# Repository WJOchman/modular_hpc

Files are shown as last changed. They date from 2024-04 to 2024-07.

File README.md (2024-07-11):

# Design & Development of a Modular High-Performance Computer (HPC)
## ELEE1119 Advanced Computer Engineering | Academic Year 2023/24
<p align="center">
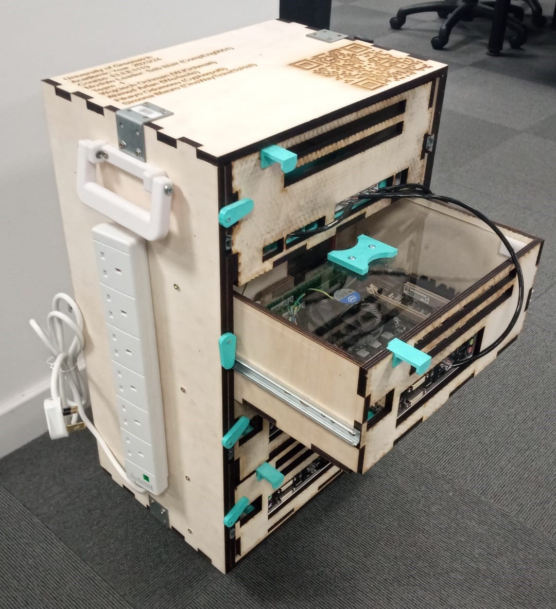
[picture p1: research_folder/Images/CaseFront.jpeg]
Front Case
  
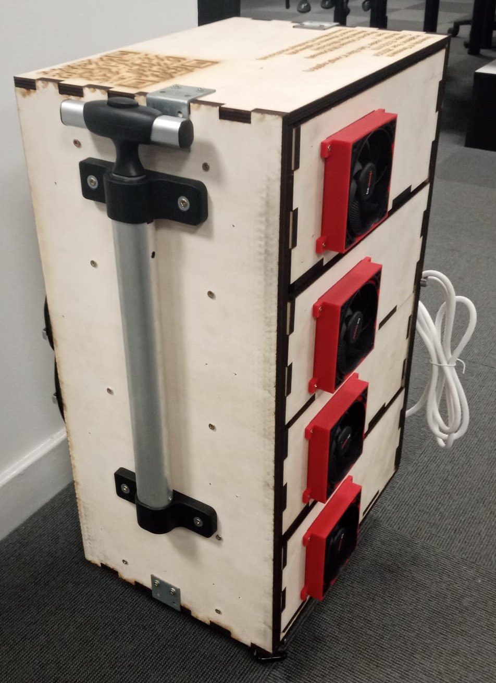
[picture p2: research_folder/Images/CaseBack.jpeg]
Back Case
  
</p>

## Table of Contents
- [Design \& Development of a Modular High-Performance Computer (HPC)](#design--development-of-a-modular-high-performance-computer-hpc)
  - [ELEE1119 Advanced Computer Engineering | Academic Year 2023/24](#elee1119-advanced-computer-engineering--academic-year-202324)
  - [Table of Contents](#table-of-contents)
  - [Video](#video)
  - [Introduction](#introduction)
  - [Setup](#setup)
  - [Design and Manufacturing](#design-and-manufacturing)
    - [Cooling overview](#cooling-overview)
  - [Software Implementation](#software-implementation)
    - [PXE Boot](#pxe-boot)
    - [OpenSSH](#openssh)
    - [Slurm](#slurm)
    - [Testing with R](#testing-with-r)
  - [Recommendations](#recommendations)
  - [Contributors](#contributors)
  - [License](#license)

## Video
<p align="center">
  <a href="https://www.youtube.com/watch?v=2bO4xLcN6Lk" title="Watch the Video">
    Video Report
  </a>
</p>

## Introduction
Welcome to the README file for the Advanced Computer Engineering module at the University of Greenwich, Academic Year 2023/24. This module is lead by Sebastian Blair. This project has been developed by `Team -1`. For full list of contributors consider the [contributors](#contributors) section.

This document provides an overview of the Design and Implementation of the High Performance Computing (HPC) System, including a brief explanation of the steps taken to develop the final products: a prototype, video and documentation demonstrating the collaborative effort and technical approach.

The HPC involves using multiple and interconnected computers in a cluster to perform complex computations. These clusters are nodes managed by schedulers to optimise resource usage. LinuxⓇ is the leading operating system for HPC. It is important to note that although a significant milestone has been reached with the creation of this prototype, there is room for further development and improvements.

## Setup
To carry out this project, the foundational components required are a Raspberry Pi (Model 4B), 3 Motherboards (ASUS CSB), and a 4/5 port switch. The Raspberry Pi acts as the head node, and the motherboards acting as compute nodes.

## Design and Manufacturing
To manufacture a copy of the HPC, an FDM (Fused Deposition Modeling) 3D Printer is necessary with a minimum hotbed size of 300 by 300mm, and a laser cutter with the minimum size of 300 by 600mm. 

PLA (Polylactic Acid) has been used as the filament of choice in this prototype, however ABS or PETG are just as appropriate. The laser cutting has been done using 9mm thick plywood, it is recommended to keep the thickness at 9mm. However, alternative materials such as acrlyic may be used instead of plywood. All CAD, STL, 3VS, and DXF design files can be located in the `hpc_case_design` folder of this repository. [Click Here](/hpc_case_design/design_readme.md) to learn more about the design and manufacturing of this project. 

### Cooling overview
Cooling for this HPC was done through a combination of various cooling methods like row cooling, forced convection and raised floor cooling. Knowing the wattage of the HPC allowed for calculation of the cooling requirements using BTU/br. With the intake of cool air, the exhaust space was calculated.</br> View the link below for more info:

- [Click Here](/hpc_case_design/cooling)

## Software Implementation
The HPC cluster here has been setup with two partitions, mycluster and mycluster2 with each having 2 nodes. The nodes are name node01, node02, node03 and node04. node01(headnode) and node04 are part of partition mycluster whereas node02 and node03 are part of partition mycluster2.

### PXE Boot
PXE (Pre-Boot Execution Environment) is a network protocol that allows a computer to boot and load its OS using resources from a server rather than local storage (USB stick, SSD, Hard Dive, etc.). This is done by leveraging the capabilities of DHCP, TFTP and NFS.
The three main packages used as DHCPD, TFTPD and NFS-Server.
DHCPD is used to create a network. TFTPD is used to create a TFTP Server and NFS is to share the OS image and kernel files. 

[Click here](/research_folder/Software/Implementation/PXE.md) to perform these prerequisite steps and PXE boot as a whole.

1. NETWORK SETUP - DHCP
   
   Firstly, all computers in the HPC setup must be able to communicate with each other. The Compute nodes (ASUS motherboards) are all connected to the head node (Raspberry pi) via LAN and are in network. Here, the DHCP (Dynamic Host Configuration Protocol) is used to allow the devices in the network (the other compute nodes) to be dynamically assigned an IP address. This simplifies the process of configuring IP addresses as it is not necessary to perform static routing and addressing on each device of the HPC. Additionally, DHCP assigns the subnet mask, default gateway, domain name server address and other configurations.
   
   To setup DHCP and get more in depth info, [click here](/research_folder/Software/Implementation/PXE.md#dhcp-server) and go to DHCP setup. 
   
<p align="center">
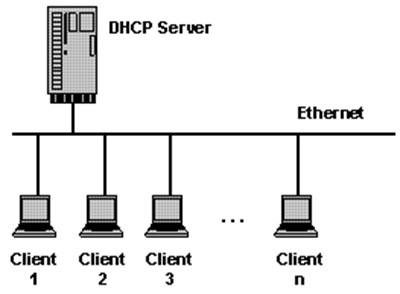
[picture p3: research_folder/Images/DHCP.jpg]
  
</p>

2. SETTING UP TFTP SERVER_
   
   TFTP (Trivial File Transfer Protocol) is a simple, lightweight protocol used to transfer files between devices on a network. It is used to specify the directory which the TFTP server needs to  server to the client. In this case, it is used to serve all the related files required for booting and show the PXE Boot menu, where users can select the operating system to install. Since all related files are stored in the tftpboot directory, this is shared using TFTP.

   To setup TFTP and get more in depth info, [click here](/research_folder/Software/Implementation/PXE.md#configure-tftp-server) and go to TFTP setup.

3. NFS
   
   After selecting the operating system, it is important for users to be able to load the images, kernel files and more. These files need to be accessible over the network. Therefore, NFS (Network File System) is used. This can be done by adding the directory which contains these files as a shared directory across the network. 

   An ISO image of an Ubuntu distribution is firstly installed and mounted. Here, a live installer of Ubuntu 20.04 is installed. It is then copied to a certain directory (ubuntu). This directory now contains all the iso files necessary to install the OS on a machine. This directory needs to be exported over the network and available to compute nodes. Hence it must be configured in the NFS exports file.

   Finally, the PXE Boot menu needs to be configured. The initrd (Initial RAM disk)and vmlinuz (kernel image) files are required to be fetched once user selects operating system. This must be specified in the Boot menu file.

   To setup NFS and get more in depth info, [click here](/research_folder/Software/Implementation/PXE.md#nfs) and go to NFS section. 

Given below is an overview of the entire process
<p align="center">
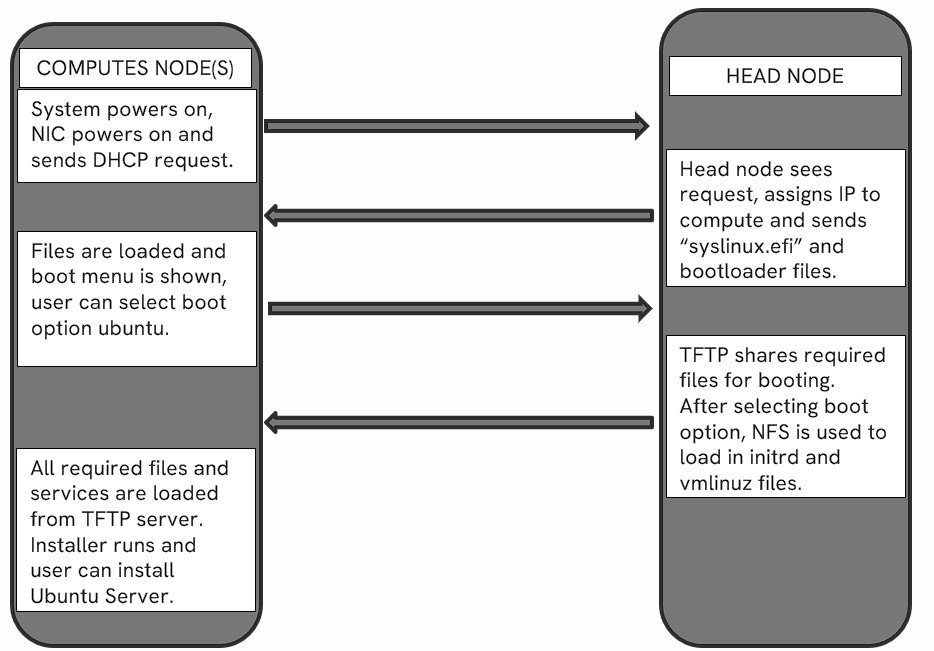
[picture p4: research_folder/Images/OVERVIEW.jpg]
Overview
  
</p>

### OpenSSH
A prerequisite for slurm, to allow secure file transfer and communication between nodes. Allows remote access to compute nodes.</br> For instructions on setting up OpenSSH [Click Here](/research_folder/Software/Implementation/OpenSSH.md#openssh-setup)

### Slurm
Slurm is a highly scalable and flexible workload manager used primarily in HPC environments. Slurm provides mechanisms for inter-task communication and coordination, allowing tasks to share data or synchronize their operations as needed.</br>
SLURM needs to be able to perform its jobs on any node of the cluster. This makes it so that each node should be able to access the same files. Therefore, a shared storage would have to be created. In this project, a 16GB USB drive connected to the head node is exported as a Network File System.

[Click here](/research_folder/Software/Implementation/Slurm.md) to do setup USB as shared storage and setup SLURM between a head node and a compute node. In our setup slurm has been setup for the 4 nodes. Slurmd runs on all nodes whereas node01 runs slurmctld.

### Testing with R

Finally, to test the SLURM setup, an R script is created which generates 10000 random datasets, these datasets are then used to create a density plot jpg. Then the script is run 50 times parallelly on a single partition.  This has been tested and run on the partition mycluster.
Therefore, 50 plots are generated at once, as shown below.

Here are some of the plots:

<p align="center">
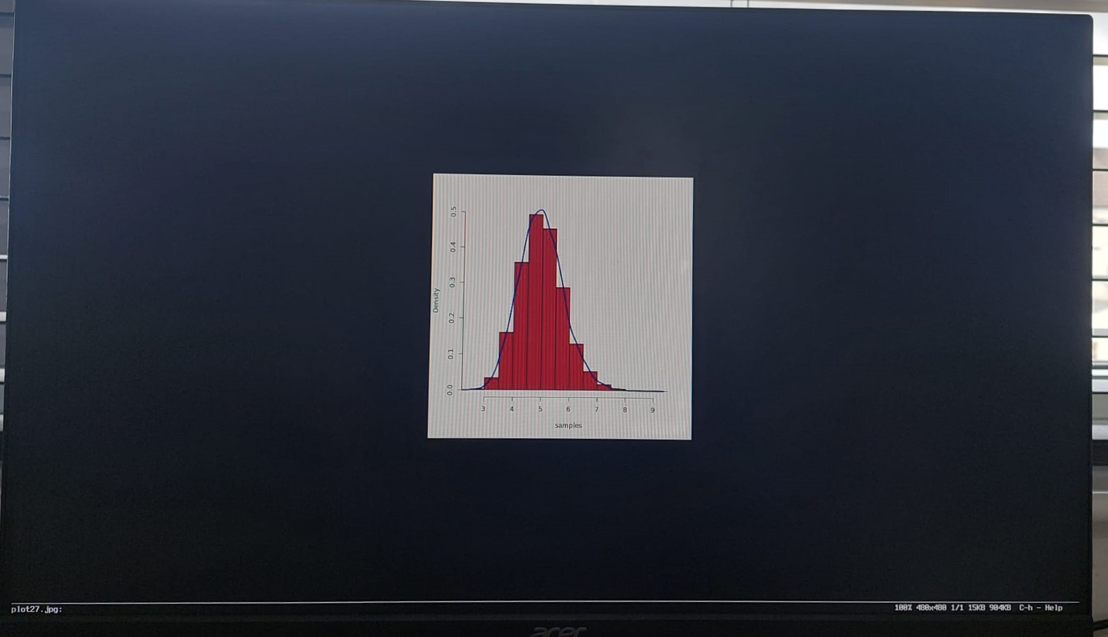
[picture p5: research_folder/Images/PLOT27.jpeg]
Plot 27
  
</p>
<p align="center">
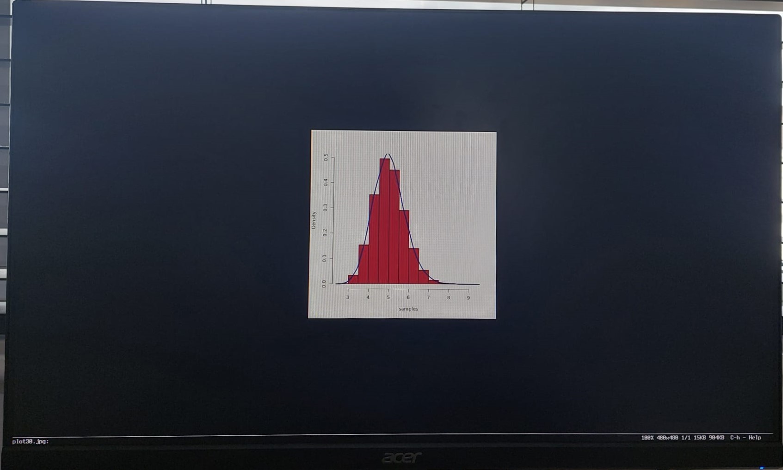
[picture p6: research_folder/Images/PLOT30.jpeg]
Plot 30
  
</p>
<p align="center">
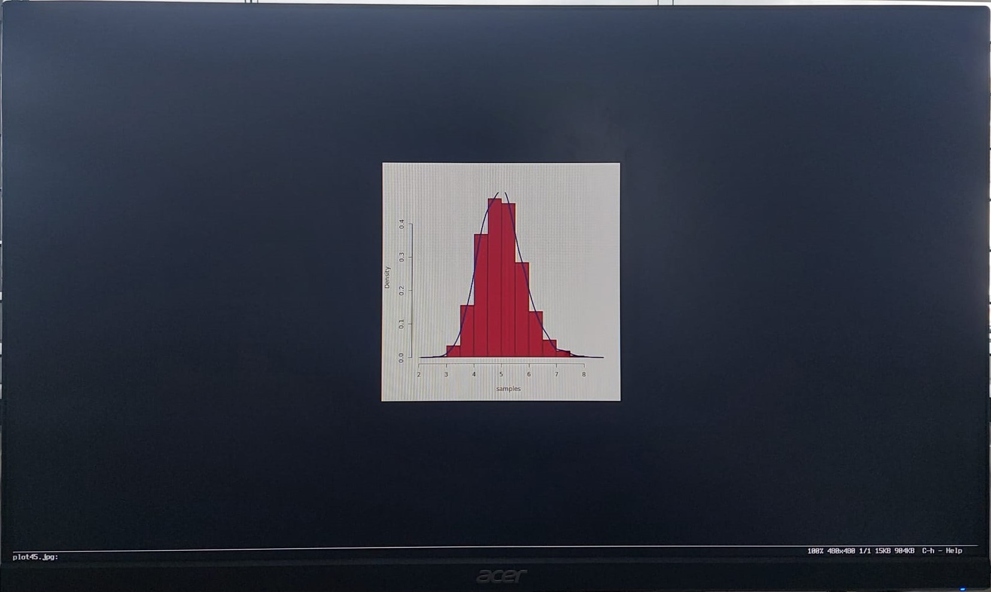
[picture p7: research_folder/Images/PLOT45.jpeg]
Plot 45
  
</p>

[Click here](/research_folder/Software/Implementation/TestRPRogram.md) to view detailed documentation and code.
As a result, SLURM was used to run a job i.e., generating plot from 10000 samples 50 times in parallel. This mimics data processing of large datasets which is a major use case of HPC clusters. 

## Recommendations
Some of the project's next steps include incorporating technologies to improve its capabilities and test its abilities. Integrating SingularityCE can simplify the deployment of complex applications in HPC and scientific computing environments, leveraging containerisation for portability and reproducibility. John the Ripper could enhance security by identifying vulnerabilities in different operating systems. Prometheus and Jaeger will facilitate the monitoring and tracking framework, offering insights into system performance and operational dynamics. Furthermore, these integrations will be relatively easy by taking advantage of Slurm's compatibility with Docker.
Users are encouraged to consult the official documentation linked below for installation guidance on these technologies.

- [SingularityCE Documentation](https://docs.sylabs.io/guides/latest/user-guide/)
- [John the Ripper Documentation](https://github.com/openwall/john/tree/bleeding-jumbo)
- [Prometheus Documentation](https://prometheus.io/docs/prometheus/latest/installation/)
- [Jaeger Documentation](https://www.jaegertracing.io/docs/1.55/getting-started/)

## Contributors
- [@Wertasile](https://github.com/Wertasile)
- [@Cypherpol0](https://github.com/Cypherpol0)
- [@OneWayTicketToHell](https://github.com/OneWayTicketToHell)
- [@WJOchman](https://github.com/WJOchman)
- [@CompEng0001](https://github.com/CompEng0001) - Lecturer

## License
<p xmlns:cc="http://creativecommons.org/ns#" >This work is licensed under <a href="http://creativecommons.org/licenses/by-nc-sa/4.0/?ref=chooser-v1" target="_blank" rel="license noopener noreferrer" style="display:inline-block;">CC BY-NC-SA 4.0</a></p>

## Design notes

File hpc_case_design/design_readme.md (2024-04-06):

# Introduction
The purpose of this file is to serve as a guideline through the hpc_case_design folder. This document will present an overview of the file structure of the folder, and what you will find in it. What technologies have been used to develop them and how you can use them.

## Table of Contents
- [Introduction](#introduction)
- [File Structure](#file-structure)
- [3D Printing Files](#3d-printing-files)
- [Laser Cutting Files](#laser-cutting-files)

## File Structure
```
├── hpc_case_design
│   ├── design_readme.md => (You are HERE!)
│   ├── cooling
│   │   ├── Cooling_Requirements.md
│   │   ├── Fan comparison.xlsx
│   │   ├── HPC Cooling solutions.md
│   │   |
│   ├── 3d_printing
│   │   ├── cad_files
│   │   │   ├── head_shelf_design.blend
│   │   │   ├── shelf_design.blend
│   │   │   ├── general-shelf
│   │   │   │   └── ...
│   │   │   ├── head-shelf
│   │   │   │   └── ...
│   │   │   ├── outer-layer
│   │   │   │   └── ...
│   │   │   └── renders
│   │   │       └── ...
│   │   ├── stl_files
│   │   │   ├── general-shelf
│   │   │   │   └── ...
│   │   │   ├── head-shelf
│   │   │   │   └── ...
│   │   │   └── outer-layer
│   │   │       └── ...
│   ├── laser_cutting
│   │   ├── 3vs_files
│   │   │   ├── inner_shelf
│   │   │   │   └── ...
│   │   │   ├── outer_shelf
│   │   │   │   └── ...
│   │   │   └── testCut.3vs
│   │   └── dxf_files
│   │   │   ├── inner_shelf
│   │   │   │   └── ...
│   │   │   ├── outer_shelf
│   │   │   │   └── ...
│   │   │   └── testCut.dxf
```

## 3D Printing Files
The folder is broken down into two main folders organised by the manufacturing methods used in this project. The first is `3D Printing`, and the second being `Laser Cutting`. 

The 3D printing folder is divided into further two sections, the first being `cad_files` which are created using Blender, an open-source computer-aided design platform, you can get Blender form here: https://www.blender.org/

The second is `stl_files` which are ready-to-slice files of the Blender CAD files. The slicing software used in the production of this prototype has been Creality Slicer, however other slicing software can be used, such as UltiMaker Cura. 

Both `cad_files` and `stl_files` are separated into three predominant categories: (a) `general-shelf` components, (b) `head-shelf` components, and (c) `outer-layer` components. 

## Laser Cutting Files
The `laser_cutting` folder is broken down into two sub-folders: (a) `3vs_files` and (b) `dxf_files`. The laser cuttable pieces had to be designed using TechSoft Design V3 software. 

These designs were exported into `.dxf` files which are then readable by the laser cutter.

## Cooling
The `cooling` folder consists of the calculations done for the HPC in BTU/hr as mentioned in the `README.md` file. It describes how and why the selected units were used and the standards for using those units. This is shown in the `Cooling_Requirements.md` file. The `Fan comparison.xlsx` file contains the comparisons for the fans used to cool the HPC. The selection criteria are displayed as column labels and the calculation for the energy (heat energy dissipated is displayed). inally, the `HPC Cooling Solutions.md` file describes the existing cooling methods used in the design for the HPC.

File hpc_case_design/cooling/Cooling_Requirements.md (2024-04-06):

# Cooling Requirements
Before a fan can be specified, the airflow required to dissipate the heat generated has to be approximated. Both the amount of heat to be dissipated and the density of the air must be known. </br>
First we would need to determine the required airflow to adequately cool the components. For this, you can use a rough estimate from the specification of our components. The case can use up a maximum of 220W of power, supplied by the PSU. Strictly for lower limit calculation, we assume that the heat load per row of our cluster is 220W (This would mean that the efficiency of the components is 0).</br> BTU/hr is  defined by the quantity of heat required to raise the temperature of 454 grams of water from 60 to 61 degrees Fahrenheit.  BTUs/hr is normally used in the definition of the cooling power of HVAC systems as well as of the heating power of fuel.</br>
It is a standard that 1watt requires 3.412BTU/hr for cooling.</br>

So, the required cooling capacity in BTU/hr would be:</br>

220 watts * 3.412 BTU/hr per watt ≈ 750 BTU/hr
#### To get the CFM requirements: 
CFM=(Cooling Capacity(BTU/hr))/(Delta T*1.08)</br>
Delta T is the temperature difference between the supply air and return air in degrees Fahrenheit.</br>
1.08 is a convenience factor use to calculate CFM / airflow.</br> This has one big problem: we don’t measure airflow by weight, but by volume. AHRI Standard air weighs 0.075 pounds per cubic foot. We can convert a volume to a weight by multiplying the volume by 0.075 lbs/ft3.</br> Another issue is that we tend to measure airflow by the minute and BTUs by the hour. You can fix that by multiplying times 60. Finally, we need the specific heat of air, which is 0.24. When you multiply the air volume by 0.075 to turn CFM into pounds per minute, multiply pounds per minute by 60 to get pounds per hour, and multiply by the specific heat of air 0.24, you end up with 1.08 (60 x .075 x 0.24 = 1.08).</br> The number is not really a constant because the volume of the air varies a lot with temperature, which changes the "magic number."</br>
CFM=(750BTU/hr)/(36°F*1.08)</br>
CFM ≈  (750BTU/hr)/38.88</br>
CFM ≈ 19.29</br>
NOTE: EDIT DELTA T TO REFLECT AIR COMING IN VS GOING OUT</br>

# Vent calculations
For proper airflow circulation, you'll need to ensure that the total cross-sectional area of the exhaust vent is equal to or greater than the cross-sectional area of the fan's inlet (or intake) area. This ensures that the airflow is not restricted, allowing for efficient cooling. </br>
Therefore: </br>
Areainlet  = π * (dinlet /2)2</br>
= π*(92/2)2</br>
= 6647.6mm2</br>

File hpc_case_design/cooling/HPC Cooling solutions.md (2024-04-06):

# HPC Cooling solutions
# Methodology </br>
Looking over various cooling methods, our team decided that combining existing techniques within our HPC architecture would be best for overall performance and optimal temperature for HPC components. The combination of row cooling, raised-floor cooling and forced convection make up the basis for cooling the HPC.

https://downloads.dell.com/manuals/all-products/esuprt_software/esuprt_it_ops_datcentr_mgmt/high-computing-solution-resources_white-papers48_en-us.pdf

## Row Cooling</br>
This implies a row-oriented cooling architecture, each cooling unit (fan) is dedicated to cooling one node (row of a module), as opposed to having a larger fan for an entire module. </br>
The benefits of having row cooling include: </br>
#### Redundancy:</br>
Individual fans provide redundancy. If one fan fails, the impact is limited to the row it serves, reducing the risk of widespread cooling failure. In contrast, a central fan failure could affect the entire cluster.</br>
#### Localized Cooling:</br>
Individual fans allow for more precise cooling control. You can adjust the airflow and cooling levels for each row based on specific requirements. This is especially beneficial in large clusters where different rows may have varying workloads or heat dissipation needs.</br>
#### Zoning and Scalability:</br>
With individual fans, it's easier to create cooling zones within the cluster. This allows for more scalable cooling solutions. You can add or remove fans based on the specific needs of different sections of the cluster.</br>
#### Efficient Power Usage:</br>
Tailoring the cooling to specific rows can lead to more efficient power usage. You can optimize the fan speed and airflow for each row based on its workload, avoiding overcooling and reducing overall power consumption.</br>
#### Better Heat Dissipation:</br>
Individual fans can be strategically placed to optimize heat dissipation from specific components on each row. This targeted cooling approach can result in more effective heat removal, preventing hotspots.</br>
#### Adaptability to Cluster Changes:</br>
As the cluster evolves, the cooling system can be easily adapted. Adding or removing nodes in a particular row can be accommodated by adjusting the corresponding fan setup without affecting the entire cluster.</br>
#### Noise Reduction:</br>
Multiple smaller fans distributed across the rows can operate at lower speeds, potentially reducing noise levels compared to a single large central fan operating at a higher speed.</br>
#### Easier Maintenance:</br>
Individual fans are often easier to access and maintain. If a fan needs replacement or maintenance, it can be done without disrupting the entire cluster.</br>
#### Customizable Airflow:</br>
Individual fans provide the flexibility to customize the airflow direction and speed for each row based on the orientation of components within that row, ensuring optimal cooling efficiency.</br>
#### Cooling Control Software:</br>
Modern HPC systems often come with sophisticated cooling control software that can manage individual fans dynamically based on real-time temperature readings. This level of control is crucial for maintaining optimal operating conditions.</br>

https://www.wwt.com/article/5-advantages-of-row-cooling-vs-room-cooling-edge-and-data-center

## Raised-floor cooling</br>
Airflow management is critical for maintaining proper operating temperatures and minimizing the risk of equipment failure. This is why we aim to implement raised-floor cooling by slightly suspending the motherboard to allow the flow of air within the plenum.
#### Flexibility in Cooling Infrastructure:
Raised floor systems provide flexibility in the placement of perforated tiles or grates.
#### Casing Isolation:
The ABS material holding up the motherboard pervents the transfer of heat to the acrylic casing helping to further isolate the heat between modules.
#### Efficient Airflow Management:
Raised floors allow for better management of airflow pathways. Air can be directed precisely to where it's needed, minimizing the mixing of hot and cold air and improving the overall cooling efficiency.
#### Minimizing Hotspots:
By delivering cool air from the raised floor directly to the HPC racks, the likelihood of hotspots (localized areas with higher temperatures) is reduced. This helps maintain a more consistent temperature throughout the HPC cluster, improving the reliability and performance of components.
#### Air Distribution:
Raised floor systems facilitate the distribution of cool air more effectively. More air can flow above and below the motherboard.

https://www.jasc.ch/why-raised-floors-are-essential-for-data-center-airflow-management

## Forced Convection
This is a type of heat transfer that requires an external source (fan) which is used to force matter (air in this context) to flow over a solid surface (the motherboard). 
#### Faster Heat Dissipation:
Forced convection provides faster and more controlled air movement. Fans actively push or pull air through the row's components, expediting the removal of heat generated by components. This faster heat dissipation is crucial for maintaining optimal operating temperatures in an HPC cluster.
#### Improved Temperature Uniformity:
Fans help distribute air more evenly across the components in the row, reducing the likelihood of hotspots. This results in better temperature uniformity within the cluster, which is essential for preventing thermal imbalances and ensuring consistent performance.
#### Enhanced Cooling Capacity:
Forced convection systems can provide a higher cooling capacity compared to relying solely on natural convection. Fans can move a larger volume of air, allowing for more effective heat transfer and cooling, especially in densely packed computing environments.
#### Adaptability to Varied Workloads:
Forced convection systems can be adjusted to accommodate varying workloads. Fans can be controlled dynamically to increase or decrease airflow based on the real-time heat dissipation needs of the HPC cluster. This adaptability is crucial for handling changing computational loads while managing power consumption.
#### Reduction of Thermal Lag:
Forced convection reduces the thermal lag associated with natural convection. The rapid movement of air helps minimize the time it takes for heat to be transferred away from components, preventing the build-up of high temperatures.
#### Mitigation of Environmental Factors:
Forced convection is less affected by environmental factors such as room temperature and air density variations. Natural convection can be influenced by these factors, leading to less predictable and potentially less effective cooling. This also aids consistent perfomance in various environments.
#### Reduced Reliance on Passive Cooling:
Forced convection reduces the dependence on passive cooling methods, which can be insufficient in handling the heat generated by high-performance computing components. Fans provide an active and reliable means of heat dissipation.

https://byjusexamprep.com/gate-me/forced-convection

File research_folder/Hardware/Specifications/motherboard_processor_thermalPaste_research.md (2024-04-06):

# ASUS CS-B Motherboard Research

This file presents an overview of the ASUS CS-B Motherboard.

## Specifications Summary
1. CPU:
    - LGA1150 socket for Intel 4th Gen Core i7/i5/i3, Pentium, and Celeron processors. 
2. Chipset:
    - Intel Q87 Express Chipset
3. Memory:
    - 4 x DIMMs, max. 32GB, DDR3 1600 / 1333 / 1066 MHz, non-ECC, un-buffered memory. 
    - Dual-channel memory architecture
4. Graphics:
    - Integrated Graphics Process
    - Multi-VGA output support: DisplayPort, DVI-D, and DVI-I ports
        - Supports DisplayPort with max. resolution of 4096 x 2160 @24Hz / 3840 x 2160 @60Hz
        - Supports DVI-D with max. resolution of 1920 x 1200 @60Hz
        - Supports DVI-I with max. resolution of 1920 x 1200 @60Hz
    - Maximum shared memory of 1024MB
5. Expansion Slots:
    - 1 x PCI Express 3.0/2.0 x16 slot
    - 1 x PCI Express 2.0 x16 slot (x4 mode)
    - 1 x PCI Express 2.0 x1 slot
    - 1 x PCI slot
    - 1 x mini PCIe (Full length, supports full/half mini card)
6. Storage:
    - Intel Q87 Express Chipset:
        - 5 x Serial ATA 6.0 Gb/s connectors
        - 1 x mSATA connector
7. LAN:
    - Intel I217LM Gigabit LAN controller
    - Realtek RTL8111G-CG Gigabit LAN controller
8. USB:
    - 4 x USB 3.0 ports 
    - 8 x USB 2.0 ports
9. TUF Components:
    - TUF 10K Ti-Cap
    - TUF Alloy Chokes
    - TUF MOSFETS
10. Rear Panel I/O Ports:
    - 1 x PS/2 Keyboard Port (purple)
    - 1 x Ps/2 mouse port (green)
    - 1 x DVI-I port
    - 1 x DVI-D port
    - 1 x DisplayPort port
    - 2 x LAN (RJ-45) ports
    - 4 x USB 2.0/1.1 ports
    - 2 x USB 3.0 ports
    - 3 x Audio jacks
11. Internal Connectors/Switches/Buttons:
    - 1 x USB 3.0 connector supports additional 2 USB 3.0 ports
    - 2 x USB 2.0 connectors support additional 4 USB 2.0 ports
    - 5 x SATA 6.9 Gb/s connectors
    - 1 x mSATA connector
    - 1 x Chassis intrusion connector
    - 1 x Clear CMOS jumper
    - 1 x 4-pin CPU fan connector
    - 2 x 4-pin chassis fan connectors (with DC)
    - 1 x Front panel audio connector (AAFP)
    - 1 x System panel connector
    - 1 x Speaker connector
    - 1 x LPT header
    - 2 x COM Headers
    - 1 x 24-pin ATX power connector
    - 1 x 8-pin ATX 12V power connector
    - 1 x DIS ME jumper
    - TPM IC onboard
12. Form Factor: 
    - MicroATX Form Factor: 9.6" x 9.6" (24.4cm x 24.4cm)

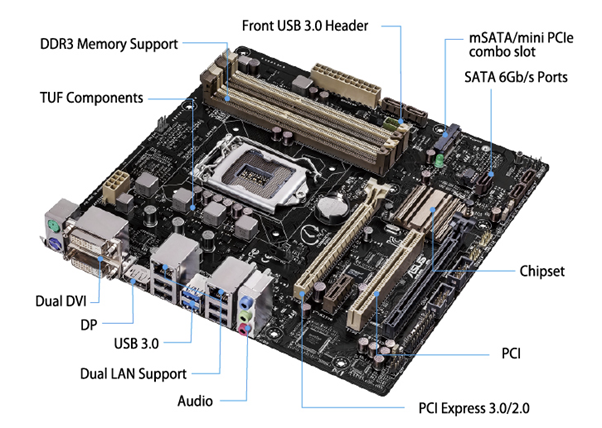
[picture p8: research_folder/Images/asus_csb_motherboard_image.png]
ASUS CS-B Motherboard Image


# Intel Core i5-4590 Processor Research

## CPU Specifications
1. Total Cores = 4
2. Total Threads = 4
3. Processor Base Frequency = 3.30GHz
4. Max Turbo Frequency = 3.70GHz
5. Cache = 6MB Intel Smart Cache
6. Bus Speed = 5 GT/s
7. TDP = 84W

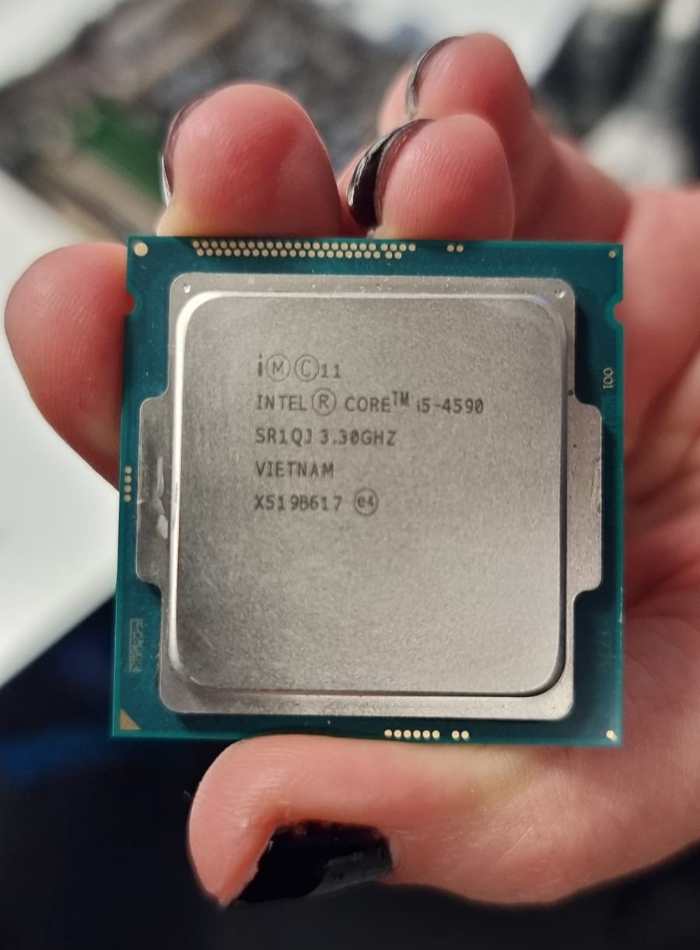
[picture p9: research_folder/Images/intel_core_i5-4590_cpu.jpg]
Intel Core i5-4590 Processor Image


# Thermal Paste Research

## StarTech Thermal Paste GR-005 Specifications
- Metal-based compound containing metal oxide
- Thermal condictivity of more than 1.93 W/m-K
- Negligible electrical conductivity
- Stable performance over a wide temperature range
- Four to six applications per tube
- Resealable syringe applicator

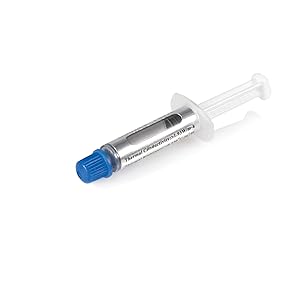
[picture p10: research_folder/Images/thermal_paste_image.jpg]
StarTech Thermal Paste GR-005


# References
1. [ASUS CS-B Motherboard Specification Document](asus_csb_motherboard_spec.pdf) [Accessed: 22/01/2024]
2. [Intel core i5-4590 Processor](https://www.intel.com/content/www/us/en/products/sku/80815/intel-core-i54590-processor-6m-cache-up-to-3-70-ghz/specifications.html) [Accessed: 22/01/2024]
3. [StarTech Thermal Paste GR-005](https://www.amazon.co.uk/StarTech-com-Metal-Thermal-Compound-Heatsink-White/dp/B00006B8DX?th=1) [Accessed: 22/01/2024]

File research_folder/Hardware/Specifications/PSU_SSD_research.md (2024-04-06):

# <u> **PSU** (Power Supply Unit) </u>

## 1. <u> Chieftec GPS-550AB A 550W </u>

* <u> TECHNICAL DATA: </u>
  - Max. Power: 550 watts;
  - Standard: ATX12V 2.0 / EPS12V;
  - PFC (Power factor correction): active;
  - Cooling system: 1 fan (120 mm);

* <u> Connectors: </u>
  - Type of connector for the motherboard: 20+4 pin;
  - Number of connectors 4-pin CPU: 1;
  - Number of connectors 8-pin CPU: 1;
  - Number of connectors 6-pin PCI-E: 2;
  - Number of connectors 15-pin SATA: 4;
  - Number of connectors 4-pin IDE: 6;
  - Number of connectors 4-pin Floppy: 1;

* <u> Current strength: </u>
<br> DC OUTPUT
  - Current on the +3.3 V: 28 A;
  - Current on the +5 V: 26 A;
  - +5V & +3,3V combined: 180W MAX.
  - Current on the +12V line 1: 18 A;
  - Current on the +12V line 2: 18 A;
  - Current on the +12V line 3: 18 A;
  - +12V line 1, +12V line 2 & +12V line 3 combined: 360W MAX.
  - +5V, +3,3V, +12V line 1, +12V line 2 & +12V line 3 combined: 534W;
  - Current line -12: 0.5 A, 6W;
  - Current on the +5 V Standby: 2.5 A, 12.5W;
  - AC-INPUT
  - 115V~/ 10A
  - 220-230V~/ 5A
  - Frequency: 47Hz-63Hz

* <u> Additional information: </u>
  - Noise level: 27 DBA;
  - Color: grey;
  - Overvoltage protection: Yes;
  - Overload protection: Yes;
  - Short circuit protection: Yes;
  - Dimensions (HxWxD): 87x150x140 mm;

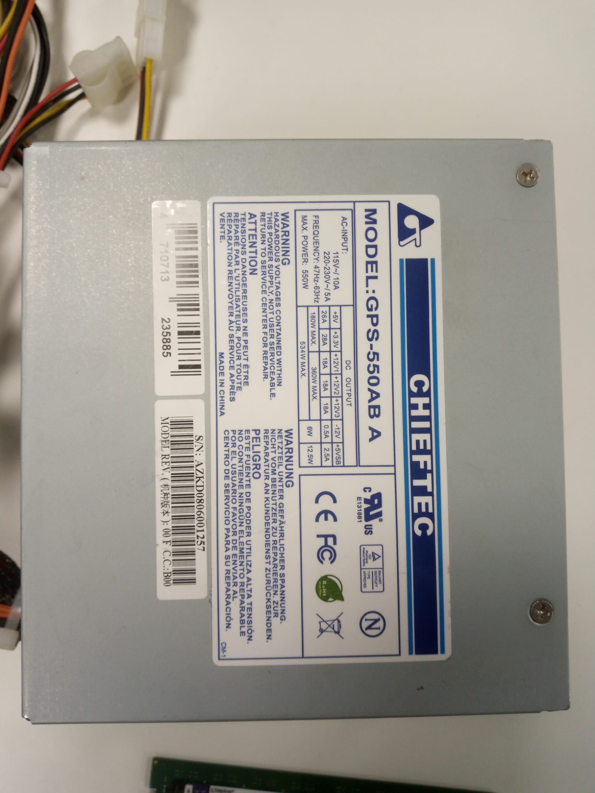
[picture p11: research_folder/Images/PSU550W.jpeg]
PSU Chieftec 550W silver image
  

## 2. <u> Chieftec CTG-750C A-80 SERIES 750W </u>

* <u> TECHNICAL DATA: </u>
  - Model: A80 750W
  - Article no.: CTG-750C
  - EAN code: 4710713239388
  - Weight (Net/Gross): 2.15kg / 2.55kg
  - AC Input: 230V / 6.3 A
  - Frequency: 50 Hz
  - Current on the +5V: 22A
  - Current on the +3,3V: 22A
  - +5V & +3,3V combined: 130W
  - Current on the +12V line 1: 30A
  - Current on the +12V line 2: 30A
  - +12V line 1, +12V line 2 combined: 675W
  - P.F.	>0,9
  - Current on the -12V: 0,3A, 3,6W
  - Current on the +5V Standby: 2,5A, 12,5W
  - Maximum Power: 750W

* <u> Connectors: </u>
  - 20+4 PIN ATX: 1
  - 8 PIN EPS(4+4): 1
  - 8 PIN PCIe (6+2): 2
  - SATA: 6
  - MOLEX/FLOPPY: 4/2

* <u> Cable length (mm): </u>
  - 20+4 PIN ATX: 450
  - 8 PIN EPS(4+4): 550
  - 8 PIN PCIe (6+2): 2x550
  - SATA: 2x 450/150/150
  - MOLEX/FLOPPY: 2x 450/150/150

* <u> Features: </u>
  - ATX12V Version: ATX 12V 2.3
  - Efficiency: >85%
  - Dimension (DxWxH): 140 mm x 150 mm x 86 mm
  - PFC: Active PFC (0,9)
  - Fan: 120mm silent fan
  - Security: AFC (Automatic Fan speed Control)
  - OPP: (Over Power Protection)
  - OVP: (Over Voltage Protection)
  - SCP: (Short Circuit Protection)
  - SIP: (Surge & Inrush Protection)
  - UVP: (Under Voltage Protection)
  - Warranty: 24 Months

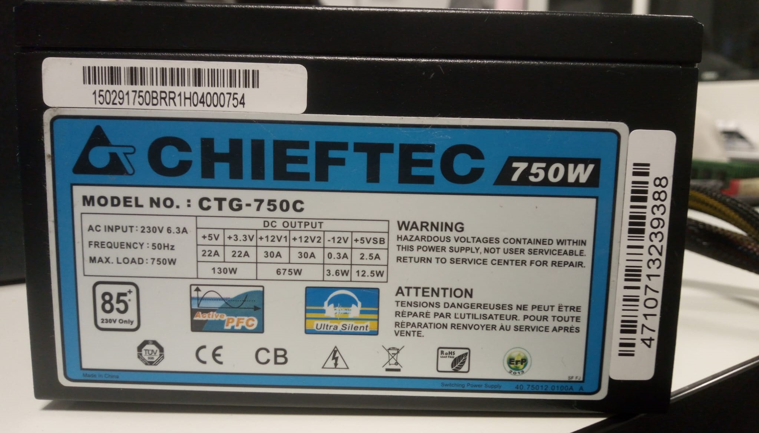
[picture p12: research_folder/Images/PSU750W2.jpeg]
PSU Chieftec 750W black image


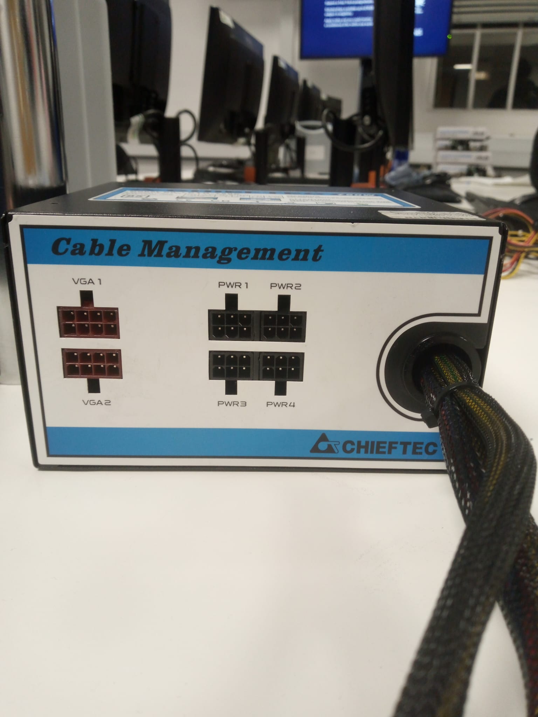
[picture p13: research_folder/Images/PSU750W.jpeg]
Cable Management of PSU Chieftec 750W black image


# <u> **SSD (Solid State Drive)** </u>

## 1. <u> Samsung Solid State Drive V-NAND 860 EVO 500GB </u>

* <u> Usage Application: </u>
  - Client PCs

* <u> Interface:  </u>
  - SATA 6 Gbps Interface, compatible with SATA 3 Gbps & 1.5 Gbps interfaces

* <u> Hardware Information: </u>
  - Capacity: 500GB
  - Controller: Samsung MJX Controller
  - NAND Flash Memory: Samsung V-NAND 3bit MLC
  - DRAM Cache Memory: 512MB LPDDR4
  - Dimensions: 100x 69.85x 6.8(mm)
  - Form Factor: 2.5 inch

* <u> Performance (Up to.): </u>
  - Sequential Read: 550 MB/s
  - Sequential Write: 520 MB/s
  - 4KB Ran. Read (QD1): 10,000 IOPS
  - 4KB Ran. Write (QD1): 42,000 IOPS
  - 4KB Ran. Read (QD32): 42,000 IOPS
  - 4KB Ran. Write (QD32): 90,000 IOPS

* <u> Power Consumption: </u>
  - Idle/ DIPM on: 50 mW
  - Active (Avg.)/ Read/Write: 2.5 W
  - Devslp: 2 mW

* <u> Reliability: </u>
  - Temp.
    - Operating: 0°C to 70°C
    - NonOperating: -45°C to 85°C
  - Humidity: 5% to 95% non-condensing
  - Shock / NonOperating: 1,500G, duration: 0.5ms, 3 axis
  - Vibration / NonOperating: 20~2,000Hz, 20G
  - MTBF: 1.5 million hours
  
* <u> Warranty: </u>
  - TBW: 300TB
  - Period: 5 year limited

* <u> Supporting Features: </u>
  - TRIM (Required OS support), Garbage Collection, S.M.A.R.T

* <u> Data Security: </u>
  - AES 256-bit Full Disk Encryption, TCG/Opal V2.0, Encrypted Drive(IEEE1667)

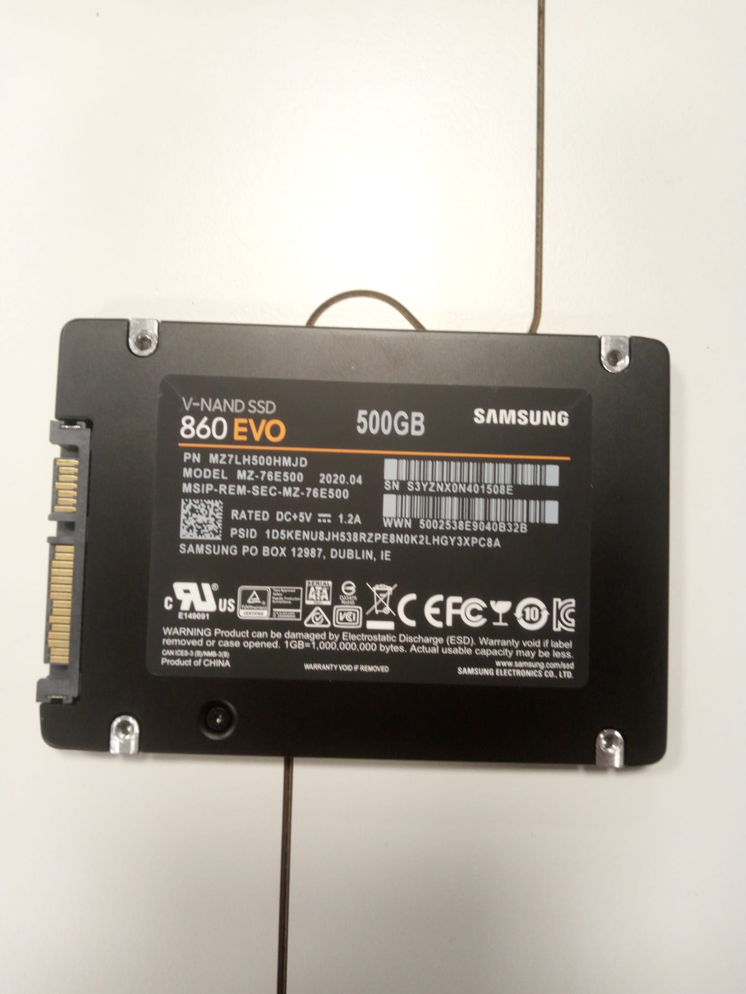
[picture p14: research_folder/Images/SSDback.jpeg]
Back of the Samsung SSD

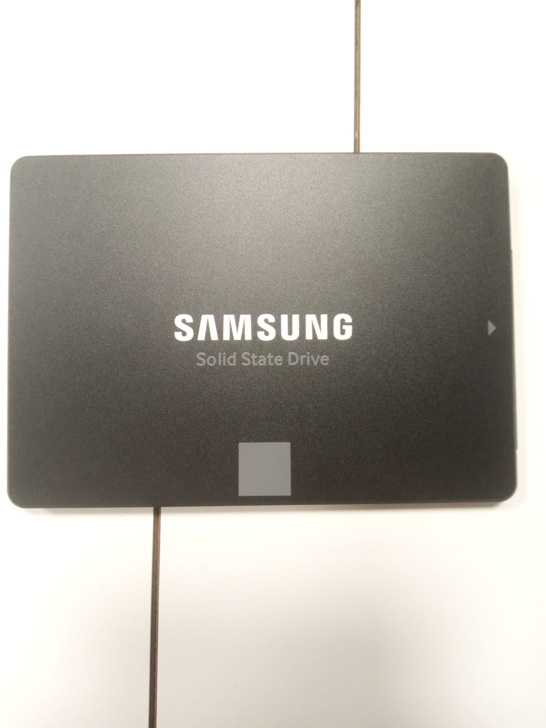
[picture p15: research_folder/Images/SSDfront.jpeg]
Front of the Samsung SSD


# References
- [Chieftec GPS-550AB A 550W](http://specsan.com/power-supply-chieftec/chieftec-gps-550ab-a-550w/) [Accessed: 22/01/2024];
- [Chieftec CTG-750C A-80 SERIES 750W](https://www.chieftec.eu/products-detail/107/A-80_SERIES/130/CTG-750C) [Accessed: 22/01/2024];
- [Samsung Solid State Drive V-NAND 860 EVO 500GB](https://download.semiconductor.samsung.com/resources/data-sheet/Samsung_SSD_860_EVO_Data_Sheet_Rev1.pdf) [Accessed: 22/01/2024];

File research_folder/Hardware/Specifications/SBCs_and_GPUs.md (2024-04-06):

# Raspberry pi 3 model B
1.	Processor (CPU): Broadcom BCM2837B0, Cortex-A53 (ARMv8) 64-bit SoC @ 1.2GHz Quad Core
2.	RAM: 1GB LPDDR2 SDRAM
3.	Wireless Connectivity:

    •	Wi-Fi: 802.11n Wireless LAN

    •	Bluetooth: Bluetooth 4.2, BLE (Bluetooth Low Energy)

4.	Ethernet: 10/100 BaseT Ethernet socket
5.	USB Ports: 4 × USB 2.0 ports
6.	Video Output:
•	HDMI (full size)
•	MIPI DSI display port
•	MIPI CSI camera port
7.	Audio: 3.5mm 4-pole audio/composite video out jack, HDMI, and a 4-pole header for stereo audio
8.	Storage: microSD card slot for operating system and data storage
9.	GPIO (General Purpose Input/Output): 40 GPIO pins
10.	Power Supply: 5V/2.5A DC power input
11.	Power over Ethernet (PoE): Enabled via HAT (Hardware Attached on Top)
12.	Operating System Support: Raspbian (officially supported), and various other Linux distributions

https://www.raspberrypi.com/products/raspberry-pi-3-model-b/

# Asus CS-B
•	CPU</br>
- Intel® Socket 1150 for 4th Generation Core™ i7/Core™ i5/Core™ i3/Pentium®/Celeron® Processors.</br>
- Supports Intel® 22 nm CPU</br>
- Supports Intel® Turbo Boost Technology 2.0</br>
    * The Intel® Turbo Boost Technology 2.0 support depends on the CPU types.

•	Chipset </br>
- Intel® Q87</br>

•	Memory
- 4 x DIMM, Max. 32GB, DDR3 1600/1333/1066 MHz Memory
- Dual Channel Memory Architecture</br>
    *Refer to www.asus.com for the Memory QVL (Qualified Vendors Lists).</br>

##	Graphic
Integrated Graphics Processor</br>
Multi-VGA output support : DVI-D/DVI-I/DisplayPort ports
- Supports DVI-D with max. resolution 1920 x 1200 @ 60 Hz
- Supports DVI-I with max. resolution 1920 x 1200 @ 60 Hz
- Supports DisplayPort with max. resolution 4096 x 2160 @ 24 Hz / 3840 x 2160 @ 60 Hz</br>
Supports up to 3 displays simultaneously
## Expansion Slots
- 1 x PCIe 3.0/2.0 x16 (beige)</br>
- 1 x PCIe 2.0 x16 (x4 mode, black)</br>
- 1 x PCIe 2.0 x1 (brown)</br>
- 1 x PCI (beige)</br>
- 1 x mini-PCIe 2.0 x1 (full-length, black) *</br>
## Storage
Intel® Q87 chipset : *</br>
5 x SATA 6Gb/s port(s), brown</br>
1 x mini-SATA 6Gb/s port(s), black</br>
Support Raid 0, 1, 5, 10</br>
Supports Intel® Smart Response Technology, Intel® Rapid Start Technology, Intel® Smart Connect Technology
## LAN
Intel® I217LM, 1 x Gigabit LAN Controller(s)</br>
Realtek® 8111G, 1 x Gigabit LAN Controller(s)
## Audio
Realtek® ALC887-VD 8-Channel High Definition Audio CODEC</br>
- Supports : Jack-detection, Multi-streaming, Front Panel Jack-retasking, Anti-pop Function
## USB Ports
Intel® Q87 chipset :
- 4 x USB 3.1 Gen 1 port(s) (2 at back panel, , 2 at mid-board)</br>

Intel® Q87 chipset :
- 8 x USB 2.0 port(s) (4 at back panel, , 4 at mid-board)

## Special Features
- TUF Components (Alloy choke, Ti-Cap. & MOSFET; certified by military-standard)</br>
ASUS Exclusive Features :
- AI Suite 3
- ASUS UEFI BIOS EZ Mode featuring friendly graphics user interface</br>
ASUS Quiet Thermal Solution :
- ASUS Fan Xpert 2</br>
ASUS EZ DIY :
- ASUS CrashFree BIOS 3
- ASUS EZ Flash 2
- ASUS MyLogo 2</br>
ASUS Q-Design :
- ASUS Q-Slot
- ASUS Q-DIMM</br>

TPM IC Onboard</br>
Bespoke Motherboard Design & Commercial Focused Features :</br>
- Layout Design: Maximized microATX layout for better thermal performance
- ASUS Watchdog Timer AP: Your system will always run, non-stop
- Total ESD Guard: Strongest electrostatic protection for maximum lifespan
- Stainless Steel Back I/O: Three times more corrosion resistance
- Overcurrent Protection: Short circuit prevention, protects your system
## Operating System Support
Windows® 8</br>
Windows® 7
## Back I/O Ports
1 x PS/2 keyboard (purple)</br>
1 x PS/2 mouse (green)</br>
1 x DVI-D</br>
1 x DVI-I</br>
1 x DisplayPort</br>
2 x LAN (RJ45) port(s)</br>
2 x USB 3.1 Gen 1</br>
4 x USB 2.0</br>
3 x Audio jack(s)</br>
## Internal I/O Ports
1 x USB 3.1 Gen 1 connector(s) support(s) additional 2 USB 3.1 Gen 1 port(s)</br>
2 x USB 2.0 connector(s) support(s) additional 4 USB 2.0 port(s)</br>
1 x LPT1 header</br>
2 x COM port(s) connector(s)</br>
5 x SATA 6Gb/s connector(s)</br>
1 x mSATA connector</br>
1 x CPU Fan connector(s)</br>
2 x Chassis Fan connector(s)</br>
1 x 24-pin EATX Power connector(s)</br>
1 x 8-pin ATX 12V Power connector(s)</br>
1 x Front panel audio connector(s) (AAFP)</br>
1 x Internal speaker connector(s)</br>
1 x System panel(s)</br>
1 x Chassis Intrusion connector(s)</br>
1 x Clear CMOS jumper(s)
## Accessories
User's manual</br>
I/O Shield</br>
2 x SATA 6Gb/s cable(s)
## BIOS
128 Mb Flash ROM, AMI BIOS, PnP, DMI2.0, WfM2.0, SM BIOS 2.5, ACPI 2.0a, Multi-language BIOS, ASUS EZ Flash 2, ASUS CrashFree BIOS 3
## Manageability
WfM 2.0, DMI 2.0, WOL by PME, WOR by PME, PXE
## Support Disc
Drivers</br>
ASUS Utilities</br>
ASUS Update</br>
Anti-virus software (OEM version)</br>
## Form Factor
mATX Form Factor</br>
9.6 inch x 9.6 inch ( 24.4 cm x 24.4 cm )
## Note
* Mini-SATA and mini-PCIe share the same slot. When mini-SATA card is inserted, mini-PCIe will not be usable, and vice versa.
* Full-length mini-PCIe slot supports full/half length mini card.
https://www.asus.com/commercial-motherboard/csb/specifications/

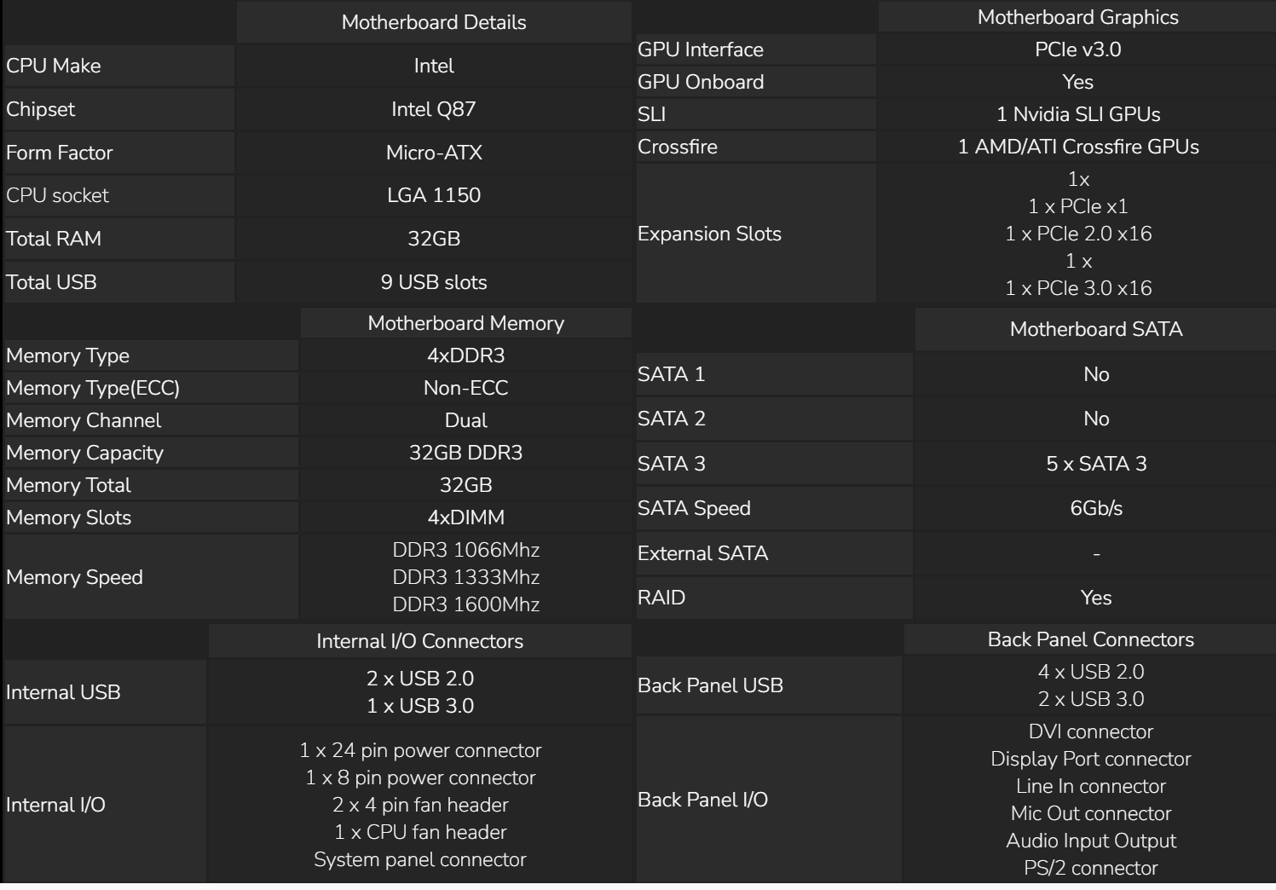
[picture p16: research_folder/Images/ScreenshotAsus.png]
ASUS CS-B Motherboard detalis
 

# Okdo Rock 4c+
•	ROCK 4C+ SBC based on the powerful Rockchip RK3399 T SoC</br>
•	Hexa-core processor with Arm® big.LITTLE™ dual Arm Cortex® A72, quad Cortex-A53 CPU, and Arm Mali™ T860MP4 GPU</br>
•	4GB 64-bit RAM and eMMC socket</br>
•	Power on/off button, integrated fan control, external antenna & audio jack</br>
•	Dual micro-HDMI ports supporting displays of up to 4Kp60 resolution</br>
•	Bluetooth 5.0 with BLE, Gigabit Ethernet and Wireless LAN</br>
•	Memory - Dual channel (64bit) 4GB LPDDR4 RAM </br>
•	Power Requirements </br>
SB C 5V/3A </br>
5V Power applied to the GPIO PIN 2 & 4</br>
The recommended power source capacity is at least 5V/3A</br>
•	USB</br>
2x USB2 HOST ports</br>
1x USB3 OTG/HOST port</br>
1x USB3 HOST port</br>
•	Connectivity</br>
802.11 b/g/n/ac (WiFi 5) Wireless LAN</br>
Bluetooth 5.0 with BLE</br>
Gigabit Ethernet
## Why is Rock Pi 4 Model C better than Raspberry Pi 3 Model B Plus?
•	3GB more RAM memory</br>
4GBvs1GB</br>
•	1.64x faster CPU speed </br>
(The CPU speed indicates how many processing cycles per second can be executed by a CPU, considering all of its cores (processing units). It is calculated by adding the clock rates of each core or, in the case of multi-core processors employing different microarchitectures, of each group of cores.)</br>
2 x 1.8GHz & 4 x 1.4GHzvs4 x 1.4GHz</br>
•	Uses big.LITTLE technology</br> 
(Using big.LITTLE technology, a chip can switch between two sets of processor cores to maximize performance and battery life. For example, when playing a game the more powerful cores will be used to increase performance, whereas checking email will use the less powerful cores to maximize battery life.)</br>
•	11mm shorter </br>
(The height represents the vertical dimension of the product.)</br>
45mmvs56mm</br>
•	1968GB more external memory supported (The maximum amount of external storage memory supported by the device.)</br>
2000GBvs32GB</br>
•	1.2 newer version of OpenGL ES </br>
(OpenGL ES is used for games on mobile devices such as smartphones. Newer versions support better graphics.)</br>
3.2vs2</br>
•	Has USB Type-C</br>
•	0.8 newer Bluetooth version</br>
5vs4.2</br>
#### Note: Neither will be used for computational purposes

# NVIDIA® QUADRO® K620
## SPECIFICATIONS </br>
•	GPU Memory - 2 GB DDR3 </br>
•	Memory Interface - 128-bit </br>
•	Memory Bandwidth - 29.0 GB/s </br>
•	NVIDIA CUDA® Cores - 384 </br>
•	System Interface - PCI Express 2.0 x16</br> 
•	Max Power Consumption - 45 W </br>
•	Thermal Solution - Ultra-Quiet Active Fansink</br> 
•	Form Factor - 2.713” H × 6.3” L, Single Slot, Low Profile</br> 
•	Display Connectors - DVI-I DL + DP 1.2 </br>
•	Max Simultaneous Displays - 2 direct, 4 DP 1.2 Multi-Stream </br>
•	Max DP 1.2 Resolution - 3840 x 2160 at 60 Hz </br>
•	Max DVI-I DL Resolution - 2560 × 1600 at 60 Hz </br>
•	Max DVI-I SL Resolution - 1920 × 1200 at 60 Hz </br>
•	Max VGA Resolution - 2048 × 1536 at 85 Hz </br>
•	Graphics APIs - Shader Model 5.0, OpenGL 4.53 , DirectX 11.24 , Vulkan 1.03 </br>
•	Compute APIs - CUDA, DirectCompute, OpenCL™</br>
•	Idle temperature – 29oC</br>
•	Load temperature – 70oC to 85oC (also optimal temperature)</br>

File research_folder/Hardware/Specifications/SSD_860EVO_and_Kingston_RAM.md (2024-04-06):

# Samsung 980evo ssd</h1>

-- Model name : MZ-76E500
-- Interfaces with 6Gb/s SATA Interface, SATA 3Gb/s interface and 1.5 interfaces
-- 2.5W when active
-- Operating Temperature 0 - 70 celcius
-- 550Mb/s and 520Mb/s Read and Write speed
-- 512Mb LPDDR4 Cache
-- Garbage Collection supported
-- 100 x 69.85 x 6.8 (mm) lbh
-- 62.37 Grams
-- Security : AES 256-bit hardware-based encryption engine

-- Motherboard has 5 6Gb/s sata ports And 1 mini sata 6Gb/s port

# KINGSTON 8GB RAM

- Manufacturer reference number : 99U5403-162.A00LF
- RAM Capacity : 8GB
- 240Pin type
- DDR3 1600MHz
- Height - 31.25mm
- 1.5V

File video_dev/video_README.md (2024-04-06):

# Introduction
The development of the video has been broken down into chapter sections similarly found in an academic engineering report. Each team member has spoken about a topic which they have contributed to within the project. The video is 20 minutes long, and the link to the video will be available in this document, and the main README.md file. 

## Table of Contents
- [Introduction](#introduction)
- [File Structure](#file-structure)
- [Video Sturcture](#video-structure)
- [Final Video](#final-video)

## File Structure
```
├── video_dev
│   ├── scripts
│   │   ├── ahmed_script.md
│   │   ├── fikayo_script.md
│   │   ├── simona_script.md
│   │   └── wojtek_script.md
│   ├── presentation
│   │   └── final_presentation.ppt
│   ├── videos
│   │   └── final_video.mp4
│   ├── video_readme.md
```

## Video Structure
The video structure is divided into the following sections alongside the assigned team member:
1. Introduction and Project Description (Wojtek)
2. System Design & Architecture (Simona)
3. nixOS Implementation (Simona)
    - Why nixOS?
    - What was tried?
    - What failed?
4. Ubuntu vs. Debian (Simona)
5. HPC Network Config and PXE Boot (Ahmed)
    - Acquiring Required Packages and OS Images
    - DHCP Network
    - Editing Config Files of RFTP and NFS for File Sharing
    - Creatiion of Boot Menu and Routing initrd and vmlinus
6. Slurm (Fikayo)
7. Housing and Cooling Solutions (Fikayo)
8. HPC Case Design and Manufacturing (Wojtek)
    - CAD Design
    - Manufacturing
        - 3D Printing
        - Laser Cutting
    - Assembly & Ethernet Crimping
    - HPC Case Final Functionality
    - Mass & Dimensions
    - Material & Labour Cost
9. Project Management (Wojtek)
10. Performance Evaluation & Discussion (Fikayo)
11. Conclusion & Future Work (Fikayo)

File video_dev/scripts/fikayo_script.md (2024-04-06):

# Fikayo Scripts
## OpenSSH
### Slide 34: OpenSSH overview
```
OpenSSH is a powerful collection of tools for the remote control, and transfer of data between, networked computers.
OpenSSH is a freely available version of the Secure Shell (SSH) protocol family of tools for remotely controlling, or transferring files between, computers. Traditional tools used to accomplish these functions, such as telnet or rcp, are insecure and transmit the user’s password in cleartext when used. 
OpenSSH provides a server daemon and client tools to facilitate secure, encrypted remote control and file transfer operations, effectively replacing the legacy tools.
```
### Slide 34: Using OpenSSH
```
To use Openssh, we would need to install the openssh-server  and configure the firewall to allow ssh connections.
Next we generate the ssh key and copy the key to the computing nodes on the network. We have used a password-less configuration for our ssh, for easier access to compute nodes.
```

## Slurm
### Slide 36: Slurm Overview
```
Slurm is a highly scalable and flexible workload manager used primarily in HPC environments. It allows users to efficiently manage and schedule computational tasks across a cluster of computing nodes. A job typically includes details such as the executable to run, required resources, and any specific job parameters. Slurm manages task separation and allocation, to prevent processing errors through a combination of job parameters, resource management mechanisms, and scheduling policies. 
Slurm provides mechanisms for inter-task communication and coordination, allowing tasks to share data or synchronize their operations as needed. Tasks can communicate through shared memory, message passing, or file-based communication, facilitating collaboration and coordination among concurrently executing tasks. 
```
## Cooling
### Slide 43: Cooling Requirements
#### Intake
```
The process of defining the cooling for this HPC is as follows.
Before a fan can be specified, the airflow required to dissipate the heat generated has to be approximated. Both the amount of heat to be dissipated and the density of the air must be known. First we would need to determine the required airflow to adequately cool the components. For this, you can use a rough estimate from the specification of our components. The case can use up a maximum of 220W of power, supplied by the PSU. Strictly for lower limit calculation, we assume that the heat load per row of our cluster is 220W (This would mean that the efficiency of the components is 0) . While different sources give nuanced methods for calculating cooling requirements, the cooling requirements were calculated using BTU/hr.
BTUs/hr are normally used in the definition of the cooling power of HVAC systems
It is a standard that 1watt requires 3.412BTU/hr for cooling. So, the required cooling capacity in BTU/hr would be as shown in the slide along with its CFM conversion.
```
#### Exhaust
```
For proper airflow circulation, you'll need to ensure that the total cross-sectional area of the exhaust vent is equal to or greater than the cross-sectional area of the fan's inlet (or intake) area. This ensures that the airflow is not restricted, allowing for efficient cooling. 
Please refer to the slide for the calculation.
```
### Slide 44: Cooling Method
```
Cooling for this HPC has taken inspiration from various cooling methods. 
The first of these is Row cooling this implies a row-oriented cooling architecture, each cooling unit (fan) is dedicated to cooling one node (row of a module), as opposed to having a larger fan for an entire module.
The second of these methods is raised floor cooling. Which requires us to raise components that generate heat such as the motherboard to allow the flow of air within the plenum.
The last of the cooling methods implemented is Forced convection, which is done using a chassis fan to transfer to transfer dissipated heat over the rows within the cluster.
```

### Slide 44: Fan comparison
```
Selecting a fan for this HPC requires comparison based on criteria like height, CFM, price, connectors, etc. To make this comparison, the options available for selection have been compared in the excel table below.
```

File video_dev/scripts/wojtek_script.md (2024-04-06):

# Wojtek Scripts
## Introduction Slides Script
### Slide 1: Introduction Slide
```
Hello and welcome to the video presentation on the development of a modular HPC for Advanced Computer Engineering at the University of Greenwich. 
```

### Slide 2: Aim and Objectives
```
The aim of this project is to design and develop a prototype of a modular HPC. The final prototype should have the ability to perform exercises such as DNA sequencing, password cracking, weather predictions, and more. 
```

### Slide 3: Table of Contents
```
This presentation is broken down into 8 chapters. We hope you enjoy the video. 
```

## Design & Manufacturing Script
### Slide 45: Case Design Introduction

```
The HPC design has been inspired by Japanese Joinery, creating interlocking ridges (or box joints) allowing for the slotting of components to minimise the use of screws and glue.

Additionally, the case has been designed to be a hybrid between a suitcase, allowing the user to transport the HPC comfortably by pulling, pushing, and lifting; and a shelving unit, dedicating an individual shelf per node, creating a separated and controlled environment for optimised cooling and organised arrangement of parts for inspection and troubleshooting. 
```

### Slide 46: Shelf Design
```
The design has been developed using Blender. The strategy was to design a single shelf and multiply that design by 4.  

However, the HPC contains two types of shelves: general, and head. The shelf design has been based around the general shelf due to its containment of the largest components: a motherboard, PSU, SD card, and a fan. Whereas, the head shelf only contains the Raspberry Pi, and the Switch with some extra room for a small keyboard.

Due to the tolerance margin of the laser cutter available, 3 types of brackets were designed to ensure that a shelf holds itself securely. The truss holds the motherboard whilst elevating it to allow for thorough air circulation and storage of up to 2 SD cards. 

Instead of the motherboard truss, the head shelf contains a case for the raspberry pi and a switch to secure their positions. 

Lastly, all shelves contain a removable shelf handle for easy opening and closing, shelf stoppers to securely close the shelves during transport, and a top wall handle. 
```

### Slide 47: Outer Case Layer
 ```
 The outer layer has also been initially designed in Blender. However, the designs had to be re-created in TechSoft Design as the laser cutter reads files in DXF format instead of STL.

A double outer layer has been designed to hold the shelves together and allow the shelf runners to be installed with top and bottom outer layers securing the casing structure. 
```

### Slide 48: 3D Printing
```
Two types of rapid manufacturing techniques have been utilised, additive and reductive manufacturing. 

In total, 54 parts have been printed, with a total print time of approximately 177 hours and 30 minutes which is equivalent to 7 days, 9 hours, 30 minutes, and approximately 1.4kg of PLA which in today’s market can cost up to £40.  

```

### Slide 49: Laser Cutting
```
Initially, acrylic was meant to be used for the case. However, a single board of acrylic of 1200mm by 600mm at 9mm thick cost £90. Whereas the same dimensions of plywood costs £26. Calculations have estimated that approximately 1.7 squared meters of plywood was required to laser cut all necessary components for a single HPC. This equates to 3 boards of plywood, however, for safety an order of 4 plywood board was placed coming up to £104. 

In total, 20 wooden pieces were laser cut for the shelves and 6 pieces for the outer layer of the shelving unit. Additionally, 4 pieces of 3mm acrylic were cut as the shelf covers for the purposes of allowing the user to inspect a single shelf without having to remove the cover first. The top cover of the outer layer has been engraved with the course, and team details alongside a QR code which takes the user to the GitHub repository of this project.  

```

### Slide 50: Assembly 
```
The assembly process took 3 days. In total, to assemble the entire structure including shelves, outer layer, caster wheels and suitcase handle, 122 M3 wooden screws were used, 74 at 15mm length, and 48 and 20mm length. 
```

### Slide 51: Final Prototype
```
The final prototype stands at just under 70cm tall with a width of 37cm and depth of 27cm. The total cost of materials and components comes up to approximately £220, which is within the £300 budget.
```

## Project Management Script
### Slide 53:
```
The workload has been divided and delegated across the team according to the strengths and interests of each member. 

A visual timeline has been developed as a guideline of the project's lifecycle. Additionally, GitHub Projects was incorporated for further visualisation using Kanban, Table, and Roadmap layouts.
```

### Slide 54: Version Control with Git and GitHub
```
All project files have been managed and controlled using Git and GitHub for version control. In total, 5 branches were used: research-branch, dev-branch, design-branch, video-branch, and main.
```

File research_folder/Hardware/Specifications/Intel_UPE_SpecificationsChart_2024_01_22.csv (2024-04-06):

UPE | Compare Intel® Products
01/22/2024 12:21:36 PM
 | Intel® Core™ i5-4590 Processor (6M Cache- up to 3.70 GHz)
Essentials
Product Collection | 4th Generation Intel® Core™ i5 Processors
Code Name | Products formerly Haswell
Vertical Segment | Desktop
Processor Number | i5-4590
Lithography | 22 nm
Recommended Customer Price | $202.00
CPU Specifications
Total Cores | 4
Total Threads | 4
Max Turbo Frequency | 3.70 GHz
Intel® Turbo Boost Technology 2.0 Frequency‡ | 3.70 GHz
Processor Base Frequency | 3.30 GHz
Cache | 6 MB Intel® Smart Cache
Bus Speed | 5 GT/s
TDP | 84 W
Supplemental Information
Marketing Status | Discontinued
Launch Date | Q2'14
Expected Discontinuance | 07/14/2017
Servicing Status | End of Servicing Lifetime
End of Servicing Updates Date | Wednesday | June 30 | 2021
Embedded Options Available | No
Datasheet | View now
Memory Specifications
Max Memory Size (dependent on memory type) | 32 GB
Memory Types | DDR3-1333/1600 | DDR3L-1333/1600 @ 1.5V
Max # of Memory Channels | 2
Max Memory Bandwidth | 25.6 GB/s
ECC Memory Supported ‡ | No
GPU Specifications
GPU Name‡ | Intel® HD Graphics 4600
Graphics Base Frequency | 350 MHz
Graphics Max Dynamic Frequency | 1.15 GHz
Graphics Video Max Memory | 2 GB
Graphics Output | eDP/DP/HDMI/VGA
Max Resolution (HDMI)‡ | 4096x2304@24Hz
Max Resolution (DP)‡ | 3840x2160@60Hz
Max Resolution (eDP - Integrated Flat Panel)‡ | 3840x2160@60Hz
Max Resolution (VGA)‡ | 1920x1200@60Hz
DirectX* Support | 11.2/12
OpenGL* Support | 4.3
Intel® Quick Sync Video | Yes
Intel® InTru™ 3D Technology | Yes
Intel® Flexible Display Interface (Intel® FDI) | Yes
Intel® Clear Video HD Technology | Yes
# of Displays Supported ‡ | 3
Device ID | 0x412
Expansion Options
Scalability | 1S Only
PCI Express Revision | Up to 3.0
PCI Express Configurations ‡ | Up to 1x16 | 2x8 | 1x8+2x4
Max # of PCI Express Lanes | 16
Package Specifications
Sockets Supported | FCLGA1150
Max CPU Configuration | 1
Thermal Solution Specification | PCG 2013D
TCASE | 72.72°C
Package Size | 37.5mm x 37.5mm
Advanced Technologies
Intel® Turbo Boost Technology ‡ | 2
Intel® Hyper-Threading Technology ‡ | No
Intel® Transactional Synchronization Extensions | No
Intel® 64 ‡ | Yes
Instruction Set | 64-bit
Instruction Set Extensions | Intel® SSE4.1 | Intel® SSE4.2 | Intel® AVX2
Intel® My WiFi Technology | Yes
Idle States | Yes
Enhanced Intel SpeedStep® Technology | Yes
Thermal Monitoring Technologies | Yes
Intel® Identity Protection Technology ‡ | Yes
Security & Reliability
Intel vPro® Eligibility ‡ | Intel vPro® Platform
Intel® AES New Instructions | Yes
Secure Key | Yes
Intel® OS Guard | Yes
Intel® Trusted Execution Technology ‡ | Yes
Execute Disable Bit ‡ | Yes
Anti-Theft Technology | Yes
Intel® Stable IT Platform Program (SIPP) | Yes
Intel® Virtualization Technology (VT-x) ‡ | Yes
Intel® Virtualization Technology for Directed I/O (VT-d) ‡ | Yes
Intel® VT-x with Extended Page Tables (EPT) ‡ | Yes

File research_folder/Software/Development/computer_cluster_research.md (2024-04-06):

# COMPUTER CLUSTERS

_computer clusters_ are designed to maximise the advantages of parallel computing

In parallel computing tasks are broken down into independent and semi independent operations for simultaneous oepration. this allows for vast increases in computing resources that can be applied to a single tasks allowing for faster execution.

For example, calculation of hours worked, taxes, etc. need to calculated for each employee in a company. Each employees calculations are assigned to separate processor to do all of it simulateneously and faster.

Hardware configuration.

## COMPUTING CLUSTERS - NODE LAYOUT
Computing clusters consist of many specialised nodes

1. HEAD NODE - This is the node into which users must logic to access resources of computer.

2. COMPUTE NODE - Contribute to vast majority of systems computing power. Cannot be accessed by users directly. Instead, Computing jobs must be created on the queue managed by head node.

3. INTERACTIVE NODE - Some computing clusters provide small number of interactive nodes which can be logged into directly. Only intended for small tasks/ short jobs. Alternatively, if interactive nodes are not present, interactive jobs can be launched on compute nodes via the queue.

## COMPUTING CLUSTERS - STORAGE LAYOUT

1. HOME DIRECTORY STORAGE - Users are given small amount of storage for config files, source codew, etc and hsould not be used for large data sets that often form input or output for computational projects.

2. PROJECT STORAGE - large input or output datasets must be stored here.
   
## QUEUES

Queue system may manage several different queues for managing differnet hardware configs

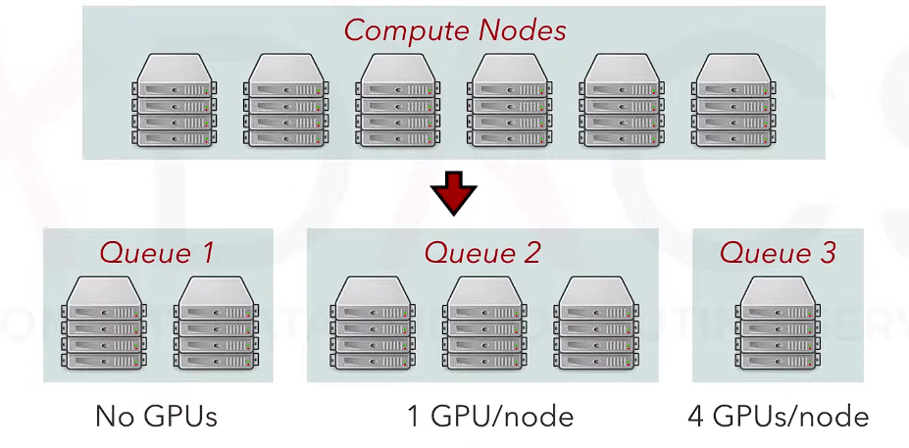
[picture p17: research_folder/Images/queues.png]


It is the responsibility of the user to send the tasks to the correct queue when sent to the queue system.

jobs are submitted to queue system via submission script specify not only the commands to be run by compute nodes but the resources needed as well. the queue system turns the script to a job and specifies job id to identify it.

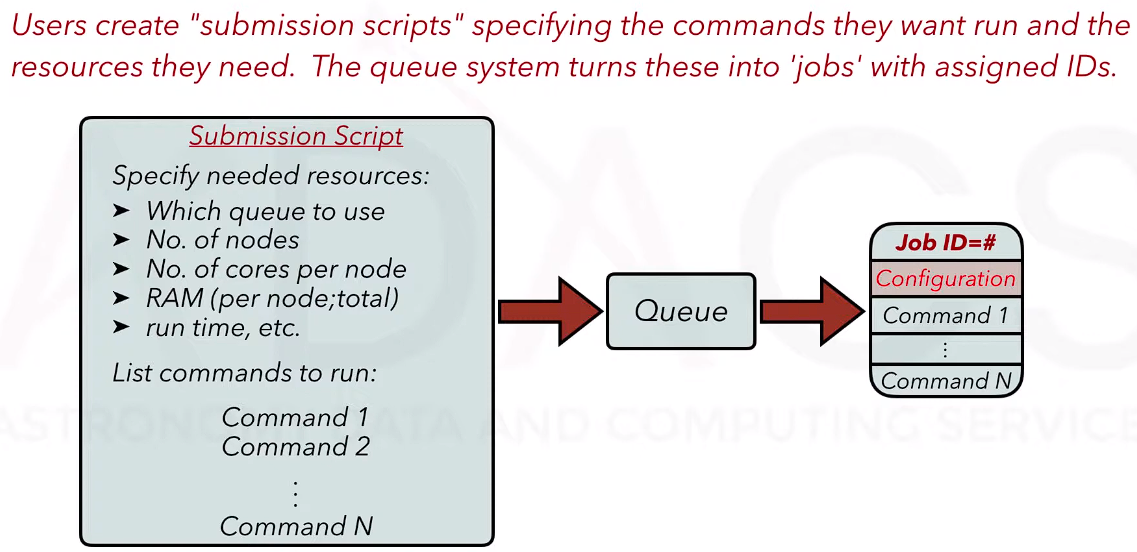
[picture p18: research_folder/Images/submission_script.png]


once jobs are created by queue system they may wait for a bit before starting depending on resources requested and degree to which cluster is being used.

its the job of the queue scheduler to monitor usage patterns of cluster and determine the optimal optimal strategy for starting jobs on computer. It seeks to maximise use of computer and manage equitable access of computer.

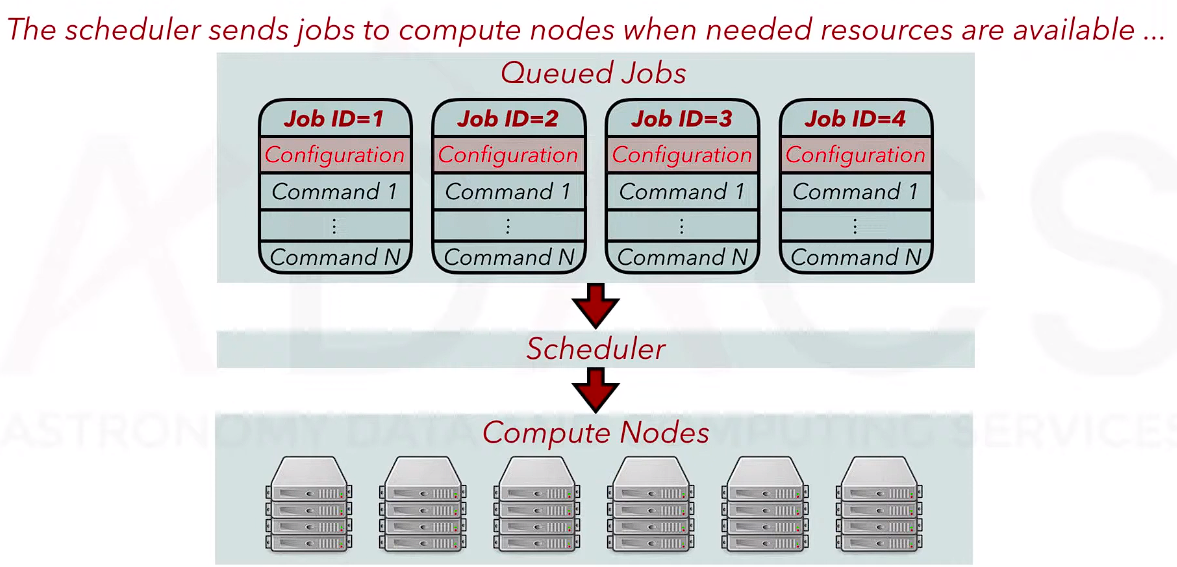
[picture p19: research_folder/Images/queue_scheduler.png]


## SCRIPTS

Operation of computing clusters can be done via a unix command line interface (CLI ) or shell scripts which package sequences of commands allowing for optional arguements. 

Shell script can be created via a text editor like vim.
then system needs to be told the text file is to be considered a executable entity
this is done by setting its permission (read, write and execute) or alternatively,  scripts can be sourced

1. when a shell is executed, a new shell is created or forked and the script is run entirely within the new shell, once complete the forked shell is destroyed and execution return to original shell. As a result, execution occurs in a clean and newly iinitialised environment. 

2. When a script is sourced, it is run within the current shell with its current environment

shell scripts can also receive parameters when executed, and within script these parameters are referenced by a dollar sign followed by a  number $1, $2, $3, ... $n.

## WORKING WITH QUEUES - SUBMISSION SCRIPTS.

submission scripts are shell scripts with additional specialised directives to specify resource requirements, job names, etc. execution privelegesn do not need to be set by chmod. These scripts are sent to the queue with a specialised command which depends on queue system used. Queue management system used here is SLURM - Simple Linux Utility Resource Manager. SLURM submission command is sbastch jobscript.

because there is no way of knowing when or where the job will execute, it is not practical to monitor output of job with the shell we submitted it in. Therefore, standard output produced by job is send to a file. By default, for a jopb with a given name and id the file will be name < name >.o< jobid >

## LOGGING IN COMPUTER CLUSTER

Computing clusters can only be accessed via head nodes, this must be achieved using secure shell (SSH) protocol. external node to compute nodes is not possible.

# SLURM

- preferred way to use a supercomputer is through submitting batch jobs toa  scheduler which governs access to compute nodes

- basic goal of queue system is maximise use of hpc and to do in a fair manner

- ease workload for users and perform complex computation

SLURM is an open source, fault tolerant and highly scalable cluster ,management and job scheduling system for large and small linux clusters.

Developed at Livermore Computing Center, and has grown into a large open source project.

## KEY FUNCTIONS

1. to give users access to rtesources for specified period of time.
   
2. provide a framework for starting, executing and monitoring work on compute nodes.
   
3. to arbitrate contention for resources by managing a queue of pending work.

## ARCHITECTURE

slurm consists of a daemon called slurmd which runs on each compoute node anda  central daemon called alurmctld running on a management node.

info can be queried via several command and can be run in the cluster.

## ENTITIES MANAGED BY SLURM DAEMONS

nodes : computer resources in slurm.

partitions - which group nodes into logical sets, jobs or allocation of resources. can be considered job queues with constraints such as job size limit, job time limit, users permitted to use it, etc.

job steps - set of tasks (maybe parallel) within the job.

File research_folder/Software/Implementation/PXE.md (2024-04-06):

# PXE - Preboot Execution Environment - Live Booting Ubuntu Over LAN

## Introduction

A PXE environment is the process of having your devices boot from its network card. PXE enables computers within a network to Install Operaing System over Network. 

In this context, an HPC cluster is being built which consists of head and compute nodes. PXE enables these compute nodes to boot over a network / boot from the head node by the head node sending the OS and other required files to the compute nodes that enter the network. A PXE server needs to be setup at head node (Raspberry Pi) and the BIOS setting on the compute nodes must be changed to boot over the network. 

When dealing with multiple machines, PXE solves the issue of having to manually install OS onto each motherboard separately. It does this by bootstrapping the machine over the network. You dont need to insert a CD or USV into the motherboards one by one.

## Components required to run PXE and configuration

Here, Ubuntu Server 20.04.5 is being booted on each compute node over LAN. Therefore, each ASUS motherboard needs to connected to the Raspberry Pi via LAN.
Given below is the file structure of the entire project. 
```
├── etc
│   ├── dhcp
│   │   ├── dhcpcd.conf
│   ├── default
│   │   ├── nfs-kernel-server
│   │   └── tftpd-hpa
│ 
├── tftpboot
│   ├── pxelinux.cfg
│   │   ├── default
│   ├── ubuntu
│   │   ├── boot
│   │   ├── casper
│   │   │    ├──initrd
│   │   │    └── vmlinuz
│   │   ├── dists
│   │   ├── EFI
│   │   ├── install
│   │   ├── isolinux
│   │   ├── md5sum.txt
│   │   ├── pool
│   │   ├── preseed
│   │   ├── ubuntu
│   ├── syslinux.efi
│   ├── ldlinux.e64
│   ├── libutil.32
│   ├── menu.c32

```

Below are the packages required:

- DHCPD (DHCP server): for creating a DHCP server
- TFTPD: for creating a TFTP server
- NFS-SERVER: for transferring images file

we also need some common files from syslinux which is a suite of bootloaders for PXE network boots.
This package contains the bootloader for the Unified Extensible Firmware Interface (UEFI) whwich is the method via which we connect the computer's firmware to the OS (UEFI IPv4). 

```
sudo apt-get install syslinux-common syslinux-efi  
```

We create a directory called tftpboot to store all configuration files

files from the syslinux library are stored here

we need few files from syslinux libraries
They are
- ldlinux.e64 - this loads the kernels
- libutil.32 - utilities required for booting
- menu.c32 - menu
- syslinux.efi

They must be copied into the tftpboot directory

```
cd /usr/lib/syslinux/modules/efi64/
sudo cp {ldlinux.e64,libutil.c32,menu.c32} /tftpboot/
cd /usr/lib/SYSLINUX.EFI/efi64
sudo cp syslinux.efi /tftpboot/
```

We also need to create a folder that will store default configuration file i.e, the entries that will appear in the boot menu. *THIS FOLDER NEEDS TO BE CALLED pxelinux.cfg.*

```
cd /tftpboot/
mkdir pxelinux.cfg
```

### DHCP server

The first step is to set up a DHCP Server.

This is done by firstly installing the dhcp package.

```
sudo apt-get install isc-dhcp-server 
```

You need to set a static IP address for your head node/ server machine (raspberry pi). This is done by accessing the network configuration files located in etc/netplan/00-installer-config.yaml. Below is configuration file. Here ethernet interface eth0 is configured as 192.168.2.1.

```
network:
  version: 2
  wifis:
    renderer: networkd
    wlan0:
      access-points
        'SSID':           
           password:'password'
      dhcp4:true
      optional:true
  ethernets:
    eth0:
      dhcp4: no
      addresses:
        - 192.168.2.1/24           
      gateway4: 192.168.2.254
```
Next we need to configure our DHCP server. This is located in /etc/dhcp/dhcpd.conf

- We have specified our network/ subnet which is 192.168.2.0 and netmask 255.255.255.0
- We also need to specify range of IP address we can assign to clients in network.
- We also need to specify the IP address of router (which is our device) - 192.168.2.1.
- We can configure the default and amximum lease time of an IP address.
- We also have configured DNS servers that are being sent from DHCP.
- Set the DHCP server as authouritative
- We need to specify where the TFTP server is, which is the Raspberry Pi which has a statically assigned IP address (192.168.2.1). This is the next-server parameter.
- We need to also specify the file that needs to be pointed at which is syslinux.efi. This means during the PXE server it will try to fetch the syslinux.efi file from the TFTP root directory which is "/tftpboot".

```  
#MY SUBNET CONFIG
subnet 192.168.2.0 netmask 255.255.255.0{
    range 192.168.2.2 192.168.2.200;
    option routers 192.168.2.1;
    option broadcast-address 192.168.2.255;
    default-lease-time 3600;
    max-lease-tine 86400;
    next-server 192.168.2.1;
    filename "syslinux.efi";
}
option domain-name "example.org";
option domain-name-servers 1.1.1.1, 1.0.0.1;

authoritative;
```

After this we need to edit the isc-dhcp-server file. Here we need to specify which interface should be listening for DHCP requests. In our case, It should be the LAN port that is connected to the compute nodes which is eth0.
It is located in /etc/default/isc-dhcp-server.

```
INTERFACESv4="eth0"
INTERFACES v6=""
```

### Configure TFTP Server
The TFTP Server that will be configured sends all related files i.e.tftpboot directory for PXE booting from the head node to compute node.
Given below is the installation of package required to setup TFTP Server.
```
sudo apt-get install tftpd-hpa
```

The configuration for TFTP Server is located in /etc/default/tftpd-hpa.

In the configuration file you must specify that the root directory for server is /tftpboot.
You must also specify the interface that serves  
Given below is the tftpd-hpa configuration file.

```
# /etc/default/tftpd-hpa
INTERFACEv4="eth0"

TFTP_USERNAME="tftp"
TFTP_DIRECTORY="/tftpboot"
TFTP_ADDRESS="0.0.0.0:69"
TFTP_OPTIONS="--secure"
```

You also need to enable UDP port 69 as that is the port address specified in the configuration file.

```
sudo ufw allow 69
```
### NFS

NFS (Network File System) IS REQUIRED FOR BOOTING THE LIVE DISTROS. It sends the required kernel and image files to the compute nodes. Firstly, we must install the nfs package.

```
sudo apt-get install nfs-kernel-server
```

We need to edit the nfs-kernel-server settings. This is located in /etc/default nfs-kernel-server.
By deafault NFS binds a number of ports for NFS usage, and those ports may be blocked by the firewall. Therefore, it is important to specify the port for NFS usage which is 40000

```
# Number of servers to start up
RPCNFSDCOUNT=8
# Runtime priority of server (see nice(1))
RPCNFSDPRIORITY=0

RPCMOUNTDOPTS="-p 40000"

# Do you want to start the svcgssd daemon? It is only required for Kerberos
# exports. Valid alternatives are "yes" and "no"; the default is "no".
NEED_SVCGSSD=""
# Options for rpc.svcgssd.
RPCSVCGSSDOPTS=""
```

Allow the port 40000 in firewall.
port 11 and 2049 are required for the portmapper and NFS service respectively.
```
sudo ufw allow 40000
sudo ufw allow 2049
sudo ufw allow 80
```

Configure the exports file. It is located in /etc/exports. Specify the directory to export and allow it to be shared to entire subnet/ network Also add options (ro, no_root_squash, no_subtree_check).

- ro - instructs read oly mounting
- no_root_squash - will allow root users to mount the nfs share.  

```
/tftpboot/ubuntu   192.168.0.0/24 (ro, no_root_squash, no_subtree_check)
```

Run the export file
```
sudo exportfs -av
```
Download the iso for the OS on the compute nodes. Ensure that the iso is ready for netbooting. It needs all the necessary files in the initrd and linux kernel (vmlinuz) for it to be able to boot. Install this in the home directory

```
cd ~
sudo wget http://releases.ubuntu com/20.04/ubuntu-20.04.6-live-server-amd64.iso
```

Mount the image and copy this to ubuntu folder
```
cd /tftpboot
mkdir ubuntu
sudo mount ~/ubuntu-20.04.2.0-desktop-amd64.iso /mnt
sudo cp -r /mnt/. ubuntu/
```

ubuntu will now get the following folders from the mounted iso file
- boot
- casper
- dists
- EFI
- isntall
- isolinux
- md5sum.txt
- pool
- pressed
- ubuntu

### PXE-BOOT MENU
Casper folder contains the intird and vmlinuz files. 

This needs to fetched when you select the Ubuntu OS from the Boot Menu. Therefore you need to edit your default file to do this.
default folder that needs to located is at /tftpboot/pxelinux.cfg.
- The LABEL to be displayed in configured - UBUNTU 20.04
- kernel file path relative to TFTP server.
- initrd (Initial RAM disk) file relative to TFTP Server.
- Configuration to botain IP address via DHCP and perform netboot via NFS. 

```
UI menu.c32

LABEL ubuntu 20.04 nfs boot
        MENU LABEL UBUNTU 20.04
        kernel ubuntu/casper/vmlinuz
        initrd ubuntu/casper/initrd
        append nfsroot=192.168.2.1:/tftpboot/ubuntu ro netboot=nfs boot=casper ip=dhcp
```
## CONCLUSION

All the necessary configurations have been made. Now all the 3 services needed to be restarted.

```
sudo systemctl restart isc-dhcp-server
sudo systemctl restart tftpd-hpa
sudo systemctl restart nfs-kernel-server
```

After this you should power on your compute node
The compute node will connect to the network and obtain an IP address.
After this the bootmenu shows up after acquiring syslinux.efi

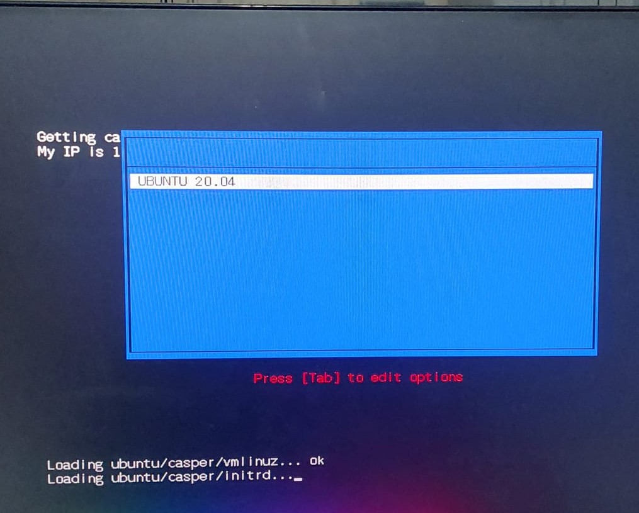
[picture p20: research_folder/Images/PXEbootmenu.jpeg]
squeue command result result of squeue command


After selecting Ubuntu20.04, the initrd and vmlinuz files load.
Eventually Ubuntu starts on the compute node after loading all dependencies.
It is by default connected to the head node as the OS and all its components were loaded due to the compute node being in the network connected to head node. Therefore, no static routing and addressing is required and compute node is ready to use.

### References

1. [Ubuntu PXE Setup](https://medium.com/jacklee26/set-up-pxe-server-on-ubuntu20-04-and-window-10-e69733c1de87)
2. [Setting up an UEFI PXE server on Linux](https://www.youtube.com/watch?v=U3RC20ANomk)
3. [How to configure PXE Network Boot Server for Ubuntu 18.04](https://www.youtube.com/watch?v=1pa4Y64y2Go&t=40s)
4. [Ubuntu Ask](https://askubuntu.com/questions/1292032/how-can-current-ubuntu-versions-be-installed-via-pxe-network-boot-and-an-automat)

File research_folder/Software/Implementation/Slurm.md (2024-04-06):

# Introduction - SLURM Workload Manager - Simple Linux Utility for Resource Management

SLURM is a Workload Manager / Scheduler. The scheduler accepts jobs and when nodes are available, they are run on the nodes. SLURM runs a controller daemon on the master node and 
# Components/steps required to run SLURM and configuration

Given below is the directory tree for the head node. All relevant files for setting up SLURM are listed below.
- etc is a standard directory, installation of all required packages and creating some files lead to the population of that directory.
- clusterfs is a populated with copies of relevant files from the head node as it is set up as a shared storage that can be accessed by all nodes. 

```
├── etc
│   ├── munge
│   │   ├── munge.key
│   ├── slurm-llnl
│   │   ├── slurm.conf
│   │   ├── cgroup.conf
│   │   └── cgroup_allowed_devices_file.conf
│ 
├── clusterfs
│   ├── munge.key
│   ├── slurm.conf
│   ├── cgroup.conf
│   ├── cgroup_allowed_devices_file.conf

```

Below are the packages required:

- NFS-SERVER: for setting up nfs on server. Download on head node
- NFS-CLIENT: for setting up nfs on client. Download on compute nodes
- SLURM CONTROLLER PACKAGES: for setting up on head node
- SLURM CLIENT PACKAGES: for setting up on compute node
- MUNGE: required for authentication on both head and compute nodes

Installation on Compute node (repeat the below for all compute nodes)
```
sudo apt install munge nfs-common slurmd slurm-client -y
```

Installation on head nodes 
```
sudo apt install munge nfs-kernel-server slurm-wlm -y
```

## Prerequisite setup

In SLURM, the scheduler expects hostname to follow a pattern, therefore the raspberry pi head node has a hostname of node01. The other compute nodes have a subsequent hostname of node02,node03,node04 and so on.
To change hostname
```
sudo hostname <enter the hostname>
```

Edit the hostname file using sudo nano /etc/hostname and add just the hostname and the rest of the file must be empty.

Edit the hosts file using sudo nano /etc/hosts

## Making a Shared Storage

For a cluster to run optimally, it is important that the job can run on any node on the cluster. Therefore, all nodes must be able to access the same files. Therefore, a 16GB USB drive is connected to the head node (raspberry pi) and that drive is shared accross the network. The drive is exported as a network file system and is mounted on all nodes so that it can be accessed.
Here, the USB drive is formatted and a d

### STEP 1

<i>Perform the below actions in the head node</i>

Locate the flash drive using ```lsblk``` command. 

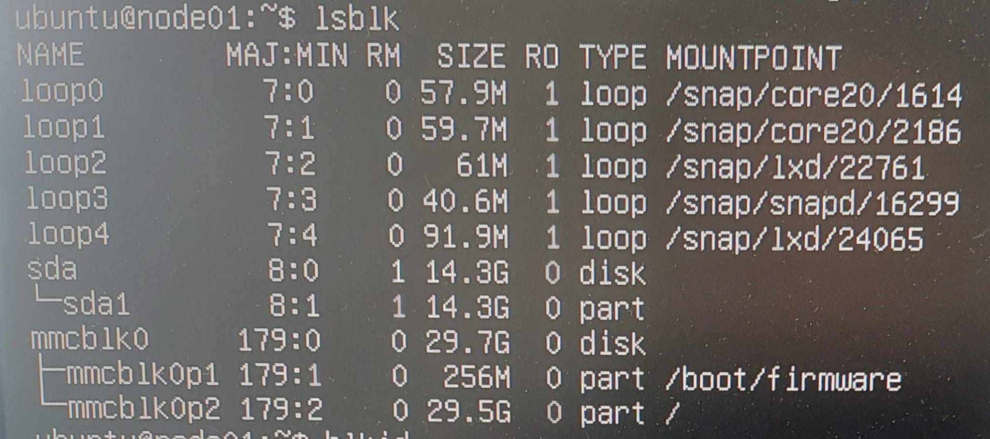
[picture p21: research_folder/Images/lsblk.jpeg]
lsblk lsblk result


The flash drive is sda. perform the following steps:

```
fdisk /dev/sda

Command (m for help): p   # to view partitions
```

Delete all exisitng flash drive partitions and create new partition
```
Command (m for help): d   # to enter mode to delete partitions

# In our case there was just one partition

Command (m for help): 1

Command (m for help): n   # To create partition

Partition number (1-<no. varies based on drive>, default 1): 1
```
When prompted with First sector and Last sector just click enter, this creates new partition of type Linux filesystem and then write w and enter to save changes.

To make our file system perform the following

```
sudo mkfs /dev/sda1
```

The above steps led to the formatting of the USB drive and creating one partition to be shared across the network.
Create a directory to mount. The USB strick is mounted onto this directory. Change the permissions to make folder accessible

```
sudo mkdir /clusterfs
sudo chown nobody.nogroup -R /clusterfs
sudo chmod 777 -R /clusterfs
```

Next, Automatic mounting needs to be setup. This enables the USB drive to mount onto the directory automatically when head node boots. Given below are the steps to perform setup automatic mounting.

Identify the UUID using command ```blkid```. Take note of the UUID for the /dev/sda directory and the value of PE. fstab file needs to be edited to mount the drive on boot. Enter the file using ```sudo nano /etc/fstab``` and add the below

```
UUID=<add your UUID here without quotations>  /clusterfs  <add your PE value here without quotations>  defaults 0 2
```

now to mount the drive in the location we specified i.e. clusterfs

```
mount /dev/sda1 /clusterfs
```

permissions need to be re-set as drive has been mounted on to it
```
sudo chown nobody.nogroup -R /clusterfs
sudo chmod -R 776 /clusterfs
```
### STEP 2
export the mounted drive so other nodes can access them. Enter the /etc/exports file using ```sudo nano /etc/exports```

<i>This tutorial assumes you have followed the PXE boot tutorial already. If not set up DHCP by following instructions here (insert link) </i>

```
# add this below the already existing line
/clusterfs    192.168.2.0/24(rw,sync,no_root_squash,no_subtree_check)
sudo exportfs -a     # to update the NFS kernel server
```
### STEP 3

Now, to mount the directory on all the other nodes perform the following. This is to be done on the compute node and repeat below steps for all compute nodes.

Create the directory onto which the directory of the USB device from the head node will be mounted. Change its permissions for accesssibility.

```
sudo mkdir /clusterfs
sudo chown nobody.nogroup /clusterfs
sudo chmod -R 777 /clusterfs
```
Once again, fstab file needs to be edited to automatically mount the drive on boot. Enter the file using ```sudo nano /etc/fstab``` and add the below
```
192.168.2.1:/clusterfs    /clusterfs    nfs    defaults   0 0
sudo mount -a
```

## CONFIGURE THE HEAD NODE
Add the hostname of all the other nodes to the /etc/hosts file
```
<ip addr of node02>      node02
<ip addr of node03>      node03
<ip addr of node04>      node04
```

Finally Configure the required SLURM files. Acquire the default SLURM Configuration and edit over it to fit the current scenario.

```
cd /etc/slurm-llnl
cp /usr/share/doc/slurm-client/examples/slurm.conf.simple.gz .
gzip -d slurm.conf.simple.gz
mv slurm.conf.simple slurm.conf
```

### 1. SET THE HEAD MACHINE INFO AND ADD CUSTOM SETTINGS FOR SCHEDULER

The first line will be slurm controller host, edit that information and add the head node info

```
SlurmctldHost=node01(192.168.2.1)
```

Edit the following to use the "consumable resources" method for resource allocation. Here each node has consumable resources such as CPU, memory, etc. and jobs are allocated based on availability of these resources

```
SelectType=select/cons_res
SelectTypeParameters=CR_Core
```

### 2. ADJUST CLUSTER NAME, ADD ALL NODES AND CREATE PARTITION

Set the cluster name under the LOGGING AND ACCOUNTING SECTION section
```
ClusterName=aceteam-1cluster
```

Add all the nodes as well
```
NodeName=node01 NodeAddr=192.168.2.1 CPUs=4 State=UNKNOWN
NodeName=node02 NodeAddr=<192.168.2.10> CPUs=4 State=UNKNOWN
```

Create a partition (group of nodes). A partition is made out of each node
```
PartitionName=partition1 Nodes=node01 Default=YES MaxTime=INFINITE State=UP
PartitionName=partition2 Nodes=node02 Default=YES MaxTime=INFINITE State=UP
```
### 3. ADJUST CGROUPS SUPPORT 
The ```/etc/slurm-llnl/cgroup.conf``` can be created to enable cgroups kernel isolation, which basically allows specifiication of what resources to user. 

```
sudo nano /etc/slurm-llnl/cgroup.conf

# enter the following in the cgroup.conf file
CgroupMountpoint="/sys/fs/cgroup"
CgroupAutomount=yes
CgroupReleaseAgentDir="/etc/slurm-llnl/cgroup"
AllowedDevicesFile="/etc/slurm-llnl/cgroup_allowed_devices_file.conf"
ConstrainCores=no
TaskAffinity=no
ConstrainRAMSpace=yes
ConstrainSwapSpace=no
ConstrainDevices=no
AllowedRamSpace=100
AllowedSwapSpace=0
MaxRAMPercent=100
MaxSwapPercent=100
MinRAMSpace=30
```

Create  file /etc/slurm-llnl/cgroup_allowed_devices_file.conf to whitelist system devices

```
sudo nano /etc/slurm-llnl/cgroup_allowed_devices_file.conf 

# enter the follwing in the cgroup_allowed_devices_file.conf file
/dev/null
/dev/urandom
/dev/zero
/dev/sda*
/dev/cpu/*/*
/dev/pts/*
/clusterfs*
```
### 4. COPY ALL FILES TO THE COMPUTE NODES
All the other nodes also need all the exact same configuration files and munge key as well. Therefore, it is copied to the shared storag diectory

```
sudo cp slurm.conf cgroup.conf cgroup_allowed_devices_file.conf /clusterfs
sudo cp /etc/munge/munge.key /clusterfs
```

### 5. ENABLE AND START ALL SERVICES

```
sudo systemctl enable munge
sudo systemctl start munge

sudo systemctl enable munge
sudo systemctl start munge

sudo systemctl enable slurmctld
sudo systemctl start slurmctld
```

## CONFIGURE THE COMPUTE NODE

Add the hostnames of all other nodes except the node itself. If working on compute node node02 then mention all other nodes except node02

```
192.168.2.1    node01
```

Lets access and copy over the required files from the shared storage into their respective directories for the compute node

```
sudo cp /clusterfs/munge.key /etc/munge/munge.key
sudo cp /clusterfs/slurm.conf /etc/slurm-llnl/slurm.conf
sudo cp /clusterfs/cgroup* /etc/slurm-llnl
```

## TESTING AND CONCLUSION

<i>Run the following on one of the compute nodes. And repeat it on all compute nodes</i>

Firstly, test munge communciation. Generate key on master node and the compute node that the command is being run on must be able to decrypt it. Run the following command.

```
ssh <username>@<masternode> munge -n | unmunge
```

The above process is verified if a reply is received saying STATUS: Success (0). If not, it is because the munge keys of the head node and compute node dont match. munge key is present in /etc/munge/munge.key

Start the SLURM daemon services
```
sudo systemctl enable slurmd
sudo systemctl start slurmd
```

After this, sinfo can be run (on the master node) to view all nodes detected and in setup along with their details

### References

1. [Slurm Basics](https://glmdev.medium.com/building-a-raspberry-pi-cluster-784f0df9afbd)

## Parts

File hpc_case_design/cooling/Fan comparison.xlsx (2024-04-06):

Site | Fan Model | Cp | DT | CFM | Density | W | q (J) | rpm | Dimension | voltage(V) | Connectors
scan.co.uk (http://www.conrad-electronic.co.uk/) | be quiet PURE WINGS 2 | 1.005 | 49 | 33.15 | 1.293 | 42.86295 | 2110.785973 | 1900 | 92x92x25 | 5 | 4-pin
scan.co.uk | Arctic F8 PWM PST Black | 1.005 | 49 | 31 | 1.293 | 40.083 | 1973.887335 | 2000 | 80x80x25 | 12 | 4-pin
scan.co.uk | Noctua NF-A8 | 1.005 | 49 | 32.6 | 1.293 | 42.1518 | 2075.765391 | 2200 | 80x80x25 | 5 | 4-pin
conrad-electronic.co.uk | Sunon PF92251V3-1000U-A99 | 1.005 | 49 | 65 | 1.293 | 84.045 | 4138.796025 | 3900 | 92x92x25 | 6 | 2 Wire leads
conrad-electronic.co.uk | Wallair 20100306 | 1.005 | 49 | 51.57 | 1.293 | 66.68001 | 3283.657092 | 3000 | 92x92x25 | 12 | 2 Wire leads

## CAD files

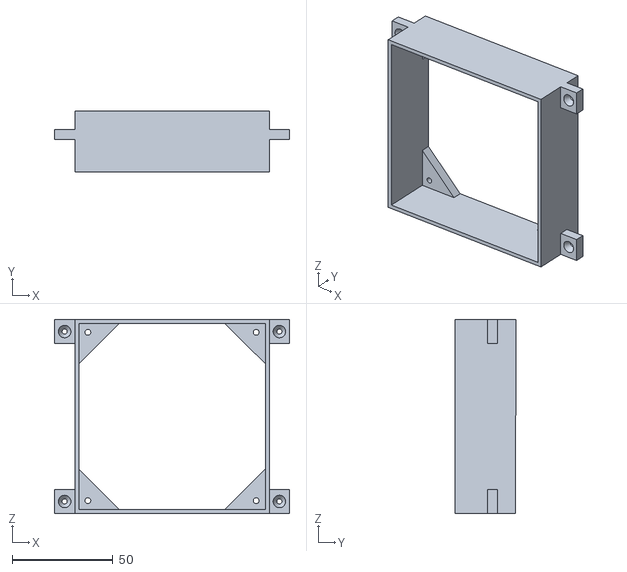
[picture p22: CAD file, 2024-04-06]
hpc_case_design/3d_printing/stl_files/general-shelf/fan_bracket.stl
116.4 x 30.0 x 96.2

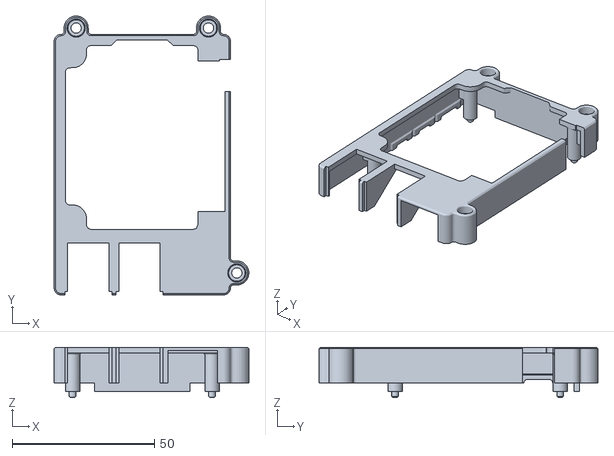
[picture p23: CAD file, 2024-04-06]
hpc_case_design/3d_printing/stl_files/head-shelf/raspi_top.stl
68.4 x 98.0 x 17.7

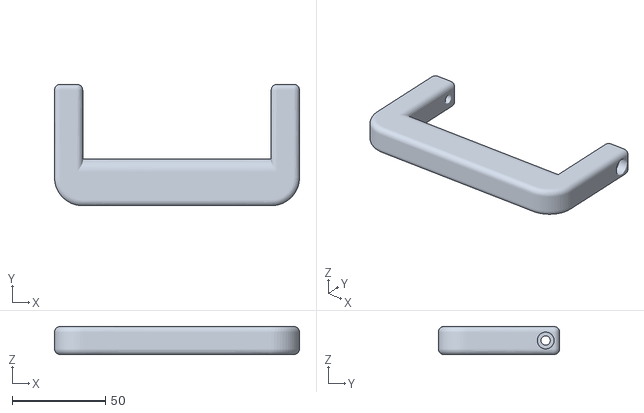
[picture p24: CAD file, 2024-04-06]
hpc_case_design/3d_printing/stl_files/outer-layer/suitcase_handle.stl
131.2 x 65.0 x 15.0

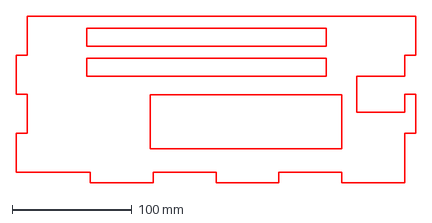
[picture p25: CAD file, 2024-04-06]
hpc_case_design/laser_cutting/dxf_files/inner_shelf/inner_shelf_back.dxf
333.0 x 139.0 mm

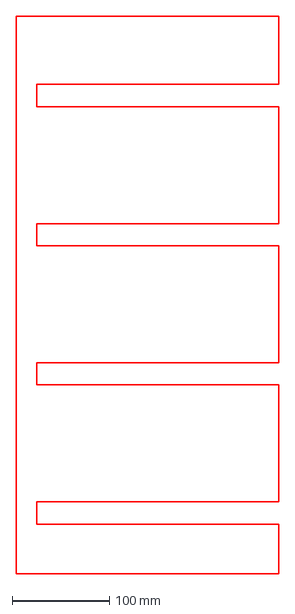
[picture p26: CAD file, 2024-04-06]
hpc_case_design/laser_cutting/dxf_files/outer_shelf/outer_layer_a.dxf
270.0 x 573.0 mm

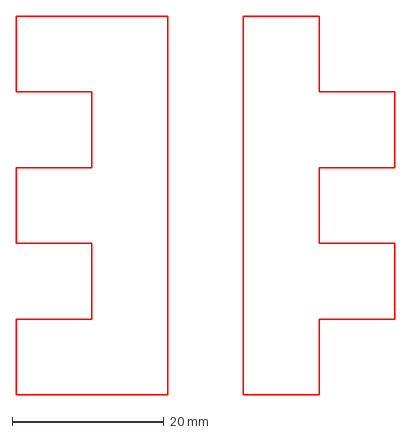
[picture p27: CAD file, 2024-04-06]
hpc_case_design/laser_cutting/dxf_files/testCut.dxf
50.0 x 50.0 mm

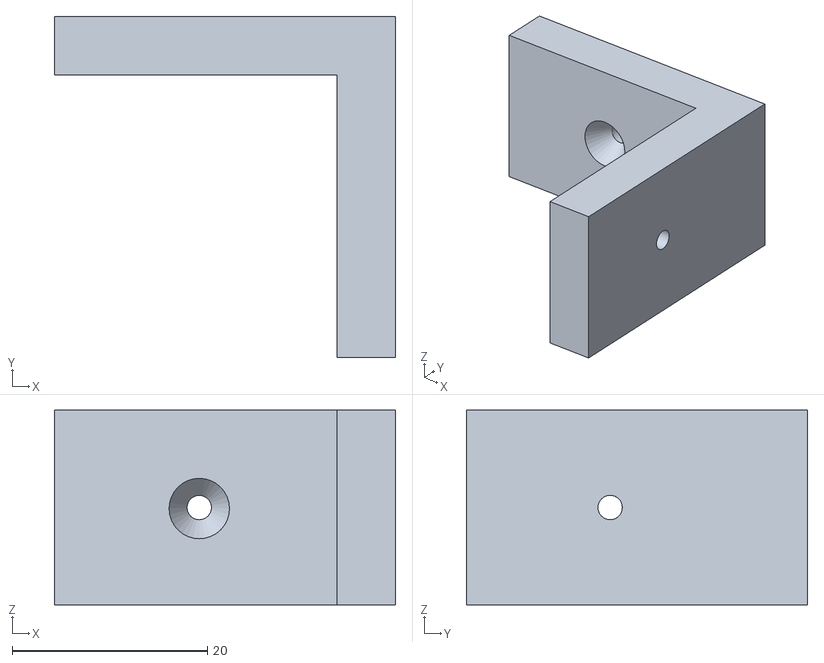
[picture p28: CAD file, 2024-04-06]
hpc_case_design/3d_printing/stl_files/general-shelf/bracket_1.stl
35.0 x 35.0 x 20.0

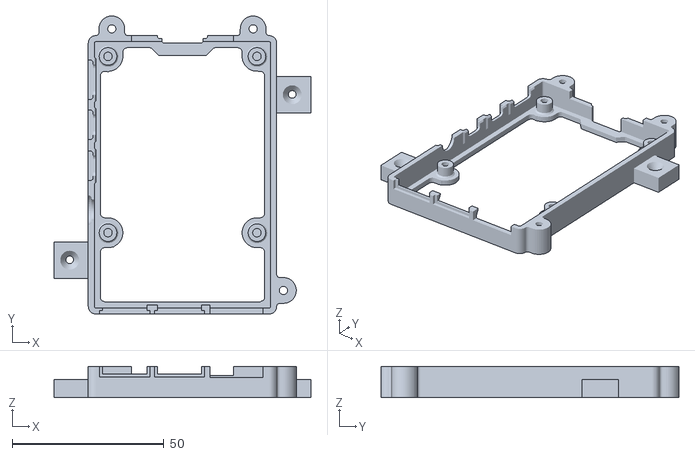
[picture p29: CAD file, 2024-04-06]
hpc_case_design/3d_printing/stl_files/head-shelf/raspi_bottom.stl
84.4 x 98.0 x 10.3

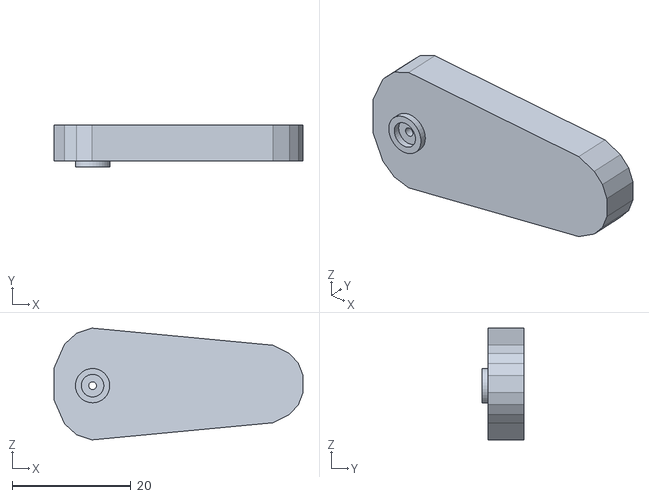
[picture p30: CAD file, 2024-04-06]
hpc_case_design/3d_printing/stl_files/outer-layer/shelf_stopper.stl
41.9 x 7.00 x 18.8

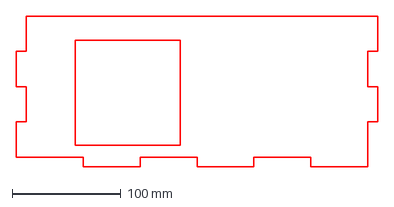
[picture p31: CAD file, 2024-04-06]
hpc_case_design/laser_cutting/dxf_files/inner_shelf/inner_shelf_front.dxf
333.0 x 139.0 mm

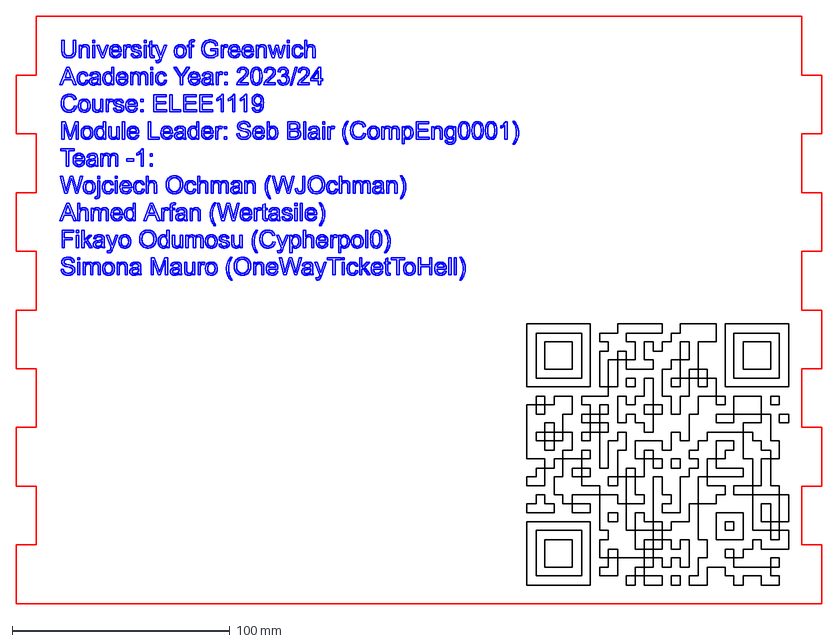
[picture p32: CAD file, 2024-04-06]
hpc_case_design/laser_cutting/dxf_files/outer_shelf/outer_layer_c.dxf
370.0 x 270.0 mm

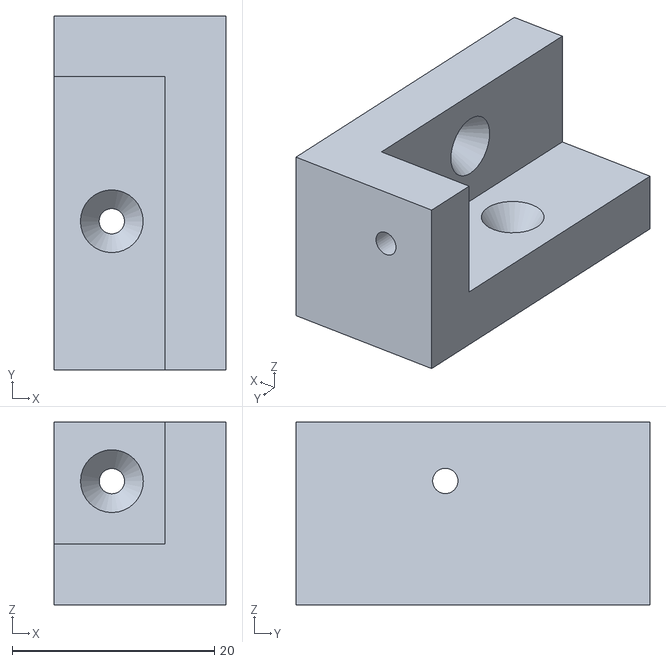
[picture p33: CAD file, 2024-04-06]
hpc_case_design/3d_printing/stl_files/general-shelf/bracket_2a.stl
17.0 x 35.0 x 18.0

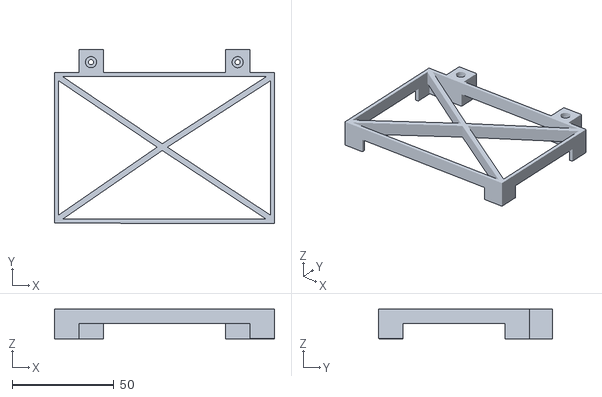
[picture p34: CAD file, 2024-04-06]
hpc_case_design/3d_printing/stl_files/head-shelf/switch_top.stl
108.0 x 85.2 x 14.5

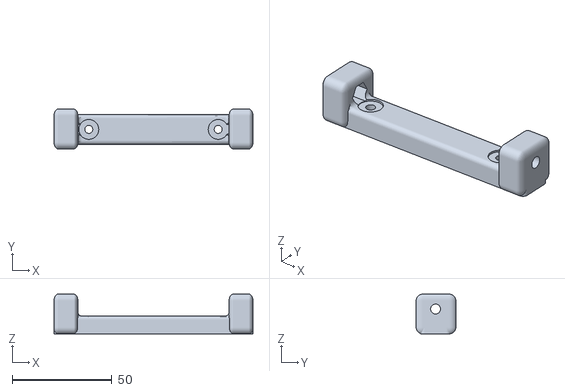
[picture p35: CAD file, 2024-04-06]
hpc_case_design/3d_printing/stl_files/outer-layer/suitcase_base.stl
100.0 x 20.0 x 20.0

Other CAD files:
hpc_case_design/laser_cutting/dxf_files/inner_shelf/inner_shelf_right.dxf
hpc_case_design/laser_cutting/dxf_files/outer_shelf/outer_layer_b.dxf
hpc_case_design/3d_printing/stl_files/general-shelf/shelf_handle.stl
hpc_case_design/3d_printing/stl_files/head-shelf/switch_bottom.stl
hpc_case_design/3d_printing/cad_files/general-shelf/bracket_1.blend
hpc_case_design/3d_printing/cad_files/general-shelf/bracket_2a.blend
hpc_case_design/3d_printing/cad_files/general-shelf/bracket_2b.blend
hpc_case_design/3d_printing/cad_files/general-shelf/bracket_3.blend
hpc_case_design/3d_printing/cad_files/general-shelf/fan_bracket.blend
hpc_case_design/3d_printing/cad_files/general-shelf/shelf_handle.blend
hpc_case_design/3d_printing/cad_files/general-shelf/top_wall_handle.blend
hpc_case_design/3d_printing/cad_files/general-shelf/truss.blend
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

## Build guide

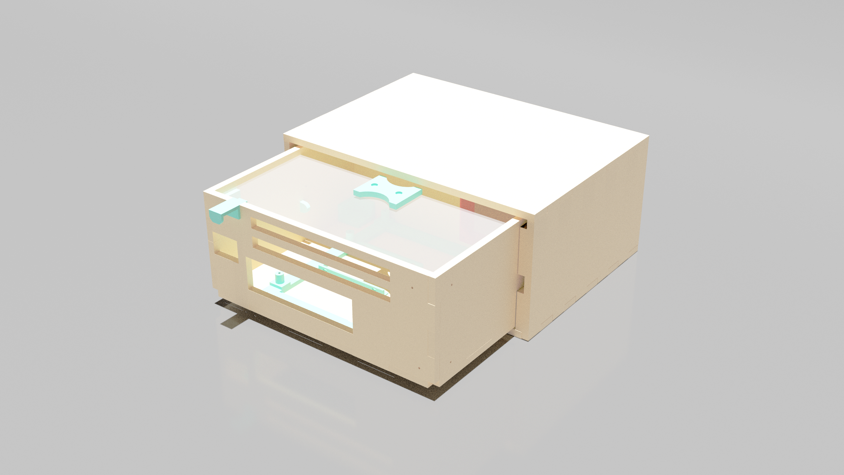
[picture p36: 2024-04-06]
hpc_case_design/3d_printing/cad_files/renders/render_2.png

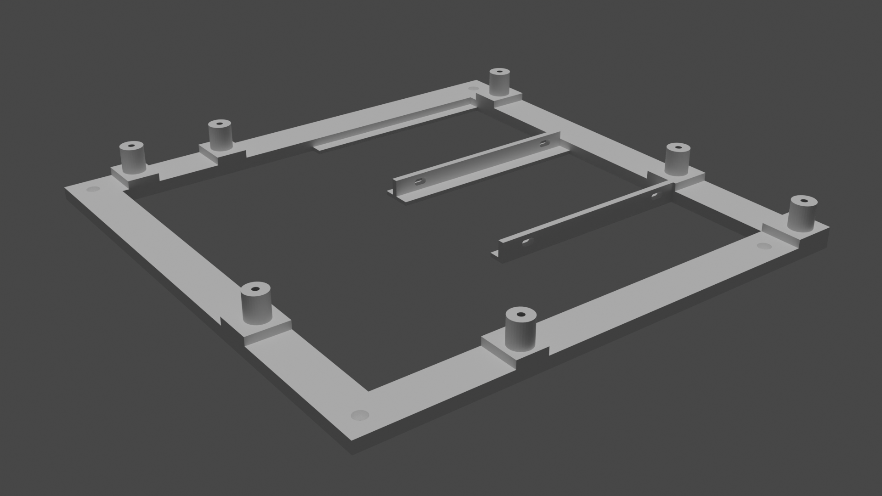
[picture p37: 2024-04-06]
hpc_case_design/3d_printing/cad_files/renders/render_7.png

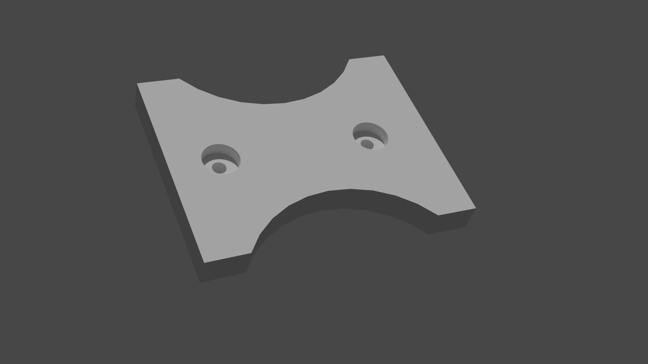
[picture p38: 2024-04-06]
hpc_case_design/3d_printing/cad_files/renders/render_9.png

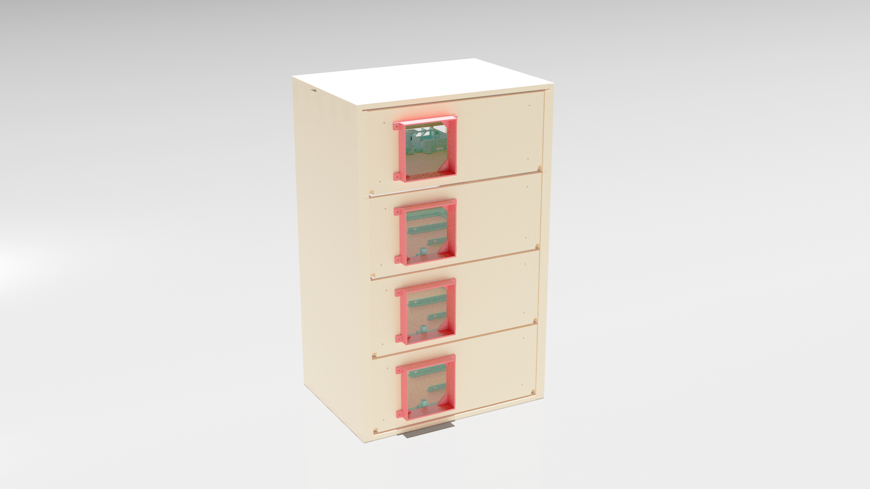
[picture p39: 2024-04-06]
hpc_case_design/3d_printing/cad_files/renders/render_3.png

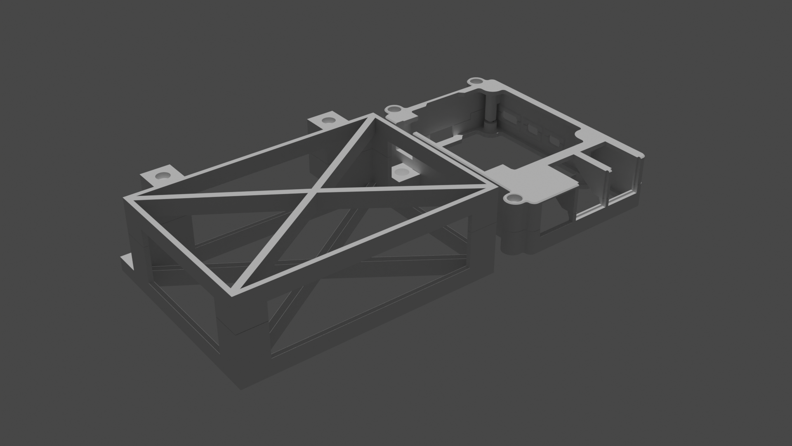
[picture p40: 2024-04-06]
hpc_case_design/3d_printing/cad_files/renders/render_5.png

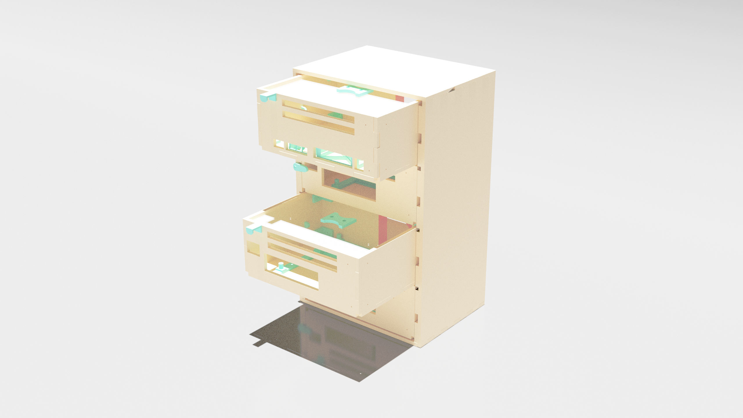
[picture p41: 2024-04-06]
hpc_case_design/3d_printing/cad_files/renders/render_4.png

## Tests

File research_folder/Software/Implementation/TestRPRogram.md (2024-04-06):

# R Program to generate random values and create graphs and histograms

## INTRODUCTION

Data processing is one of the main use cases of HPC Clusters.R is a programming language for statistical programming Therefore, a simple R program has been built which generate random values following a normal distribution and creates a histogram and graph of those values. The cluster setup is going to be used by ucreating a script to generate 50 randomly generate normal distribution graphs and histogram as images to a folder. In this test the ehad node and one compute node (node04) have been used 

## Components required to generate and run program

In the previous SLURM setup tutorial, a shared directory by mounting a USB drive was created called ```/clusterfs```. Therefore the directory R program generated, the script and results of running the script are stored in the shared storage.

```
├── clusterfs
│   ├── normal
│   │   ├── generate.R
│   │   ├── submit.sh
│   ├── plots
│   │   ├── plto1.jpg      
│   │   ├── plot2.jpg
│   │   ├── .....
│   │   ├── plot49.jpg
│   │   └── plot50.jpg
│ 
```

R needs to be installed on each node. This can be done using srun command on head node

```
sudo su -    // enter super user/root user
srun --nodes=2 apt install r-base -y
```

## R Program

The R program is going to generate graphs based on 10000 samples.
The R program is called ```generate.R``` so we create file 

```sudo nano /clusterfs/normal/generate.R```

The R program does the following
- ```arg = commandArgs(TRUE)``` saves the cmd line arguement passed which is the job id number.
- NA is replicated 10000 times to to create an empty array samples with 10000 empty slots.
- For loop to iterate over each array item and save the result of ```mean(rexp(40, 0.2)).
- ```mean(rexp(40, 0.2))``` generate 40 random values following an exponential distribution with a range of 0.2. The mean of the values is found and stored in an iteration of samples array (stored as an array item). This is repeated 10000 times.
- ```jpeg(paste('plots/', arg, '.jpg', sep=""))``` produces a new jpg file to save the generated graph into. the jpg file will have the name plots/< arg >. Therefore if we run the job 50 times, 50 jpg will be generated corresponding to job id.
- ``hist`` and ```lines``` are used to generate histogram and plot the line.

```
arg = commandArgs(TRUE)
samples = rep(NA, 100000)
for ( i in 1:100000 ){ 
    samples[i] = mean(rexp(40, 0.2)) 
}

jpeg(paste('plots/', arg, '.jpg', sep=""))
hist(samples, main="", prob=T, color="darkred")
lines(density(samples), col="darkblue", lwd=3)
dev.off()
```

## Script Creation
A script needs to be created to submit the job to our partition. The script is named submit.sh and file is created 

```sudo nano /clusterfs/normal/submit.sh```

In the script it is specified to
- run the program using any 1 node but using a single core.
- The partition to be used is also specified.
- After this, the directory is changed to the directory where the SLURM job script was submitted using ```cd $SLURM_SUBMIT_DIR```
- a directory named plots is created 
- R code generate.R is executed where plots are generated with different names based on its jobid. This is done using ```plot$SLURM_ARRAY_TASK_ID```.
- Example: If job ID is 16, plot would have name plot16.jpg.

## Running the Job

The script which handles the running generate.R and storing it in its appropriate location is used and run 50 times.

```
batch --array=[1-50] submit.sh
```

As a result the script will be run 50 times and 50 different plots are generated.
Running squeue shows:

!
<img src="../../Images/squeue.jpeg" alt="squeue command result" title="result of squeue command" width="300"/>

above, multiple jobs are running parallelly and are using either of the nodes.
The plots folder has 50 images as it is generated 50 times and 50 slurm outputs are made.

Given below is the output for 3 different plot images. As samples are random, there are slight variations in all of them.

<img src="../../Images/PLOT27.jpeg" alt="Plot27" title="Plot 27 from the 50 unique plots generated" width="300"/>
<img src="../../Images/PLOT30.jpeg" alt="Plot30" title="Plot 30 from the 50 unique plots generated" width="300"/>
<img src="../../Images/PLOT45.jpeg" alt="Plot45" title="Plot 45 from the 50 unique plots generated" width="300"/>

### Reference
1. [Testing with R](https://glmdev.medium.com/building-a-raspberry-pi-cluster-aaa8d1f3d2ca)
